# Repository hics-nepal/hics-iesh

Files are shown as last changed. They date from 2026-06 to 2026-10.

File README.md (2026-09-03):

# HICS IESH v0.1

> **Institute-level context: `~/Documents/HICS/hics-docs/`** (start at `README.md`; folder
> map in `HICS-MAP.md`). Two decisions there affect this repo directly: **G9/D28** —
> installed school stations are calibrated on every channel that can be, with MQ staying a
> labelled proxy; and **G10** — this repo's `curriculum/` (5 modules, 25+ CDC-aligned
> activities) is to be *unified* with the learning platform, not duplicated. See
> `hics-docs/LEARNING-PLATFORM.md` §2–3.

> **⚠ Deploying or debugging a station? Read [`HANDOFF.md`](HANDOFF.md) first.**
> A live diagnosis on 2026-09-03 found the station had never logged a usable day of data:
> a continuous 5 V undervoltage, sensors dropping off their buses, and firmware that logged
> a dead sensor's last value forever (~46 % of the soil column was garbage that reached the
> website). The firmware is fixed; the hardware rebuild is not started. `HANDOFF.md` has the
> **[`HANDOFF.md`](HANDOFF.md) is the single document for that work** — the faults with their
> evidence, the repos and where truth lives, the rebuild, and what is still unverified.
> `docs/drawings/` has the wiring schematic and perfboard layout.

**Himalayan Institute for Contextual Sciences — Integrated Environmental Smart Hub**

An offline-capable environmental monitoring station built on Raspberry Pi. Collects live atmospheric, air quality, and soil data; streams it to a web dashboard; and delivers Nepal CDC-aligned science activities for Grades 6–Undergraduate.

---

## Hardware

| Component | Sensor / Module | Interface |
|---|---|---|
| Air temp & humidity | DHT22 | GPIO 23 |
| Barometric pressure | BMP280 | I2C 0x76 |
| OLED display | SH1106 128×64 | I2C 0x3C |
| Real-time clock | DS3231 | I2C 0x68 |
| Soil temperature | DS18B20 | 1-Wire GPIO 4 |
| Soil moisture | Capacitive (MCP3208 CH2) | SPI |
| CO gas | MQ-7 (MCP3208 CH0) | SPI |
| Air quality | MQ-135 (MCP3208 CH1) | SPI |
| Sky camera | RPi Camera v1.3 OV5647 + fisheye | CSI |
| ADC | MCP3208 8-ch | SPI CE0 |

---

## Quick Start

**Flash a new SD card and have the RPi fully running in one command:**

```bash
# Insert SD card, then:
sudo bash flash.sh --wifi-ssid "YourNetwork" --wifi-password "YourPassword"
```

Then insert the card into the RPi, connect power, and wait 5–10 minutes. Done.

> **Hostname:** The RPi will be reachable at `iesh.local` on any network it joins.

---

## Flashing an SD Card

### What `flash.sh` does

1. Flashes Raspberry Pi OS to the SD card
2. Enables SSH and creates the `pawan` user
3. Configures WiFi
4. Copies all HICS code to the card
5. Installs a first-boot service that automatically installs all dependencies and starts the HICS services on first power-on

The OS image expands to fill the entire SD card on first boot — a 128 GB card will use all 128 GB.

### Requirements

- Linux machine with the SD card inserted
- `sudo` access
- Tools: `dd`, `xzcat` (`xz-utils`), `rsync`, `partprobe` (`parted`)
- Raspberry Pi OS image (`.img` or `.img.xz`) — download from [raspberrypi.com/software/operating-systems](https://www.raspberrypi.com/software/operating-systems/) or use the one in `~/Downloads`

### Usage

```bash
# Basic (will prompt for WiFi)
sudo bash flash.sh

# Full options
sudo bash flash.sh \
  --image ~/Downloads/2026-04-21-raspios-trixie-arm64-lite.img.xz \
  --device /dev/sda \
  --wifi-ssid "MyNetwork" \
  --wifi-password "MyPassword" \
  --hostname "hics-iesh" \
  --station-id "IESH-KMC-001" \
  --api-key "<key issued by himalayansciences.org>"

# Only flash OS without copying HICS code
sudo bash flash.sh --skip-code
```

| Option | Default | Description |
|---|---|---|
| `--image PATH` | auto-detect `~/Downloads/*.img.xz` | OS image file |
| `--device DEV` | `/dev/sda` | SD card device (confirmed before writing) |
| `--wifi-ssid` | (prompted) | WiFi network name |
| `--wifi-password` | (prompted) | WiFi password |
| `--hostname` | `hics-iesh` | RPi hostname |
| `--password` | random, printed at end | `pawan` user password — per-device, never shared |
| `--station-id` | (none) | Station ID for cloud sync, e.g. `IESH-KMC-001` |
| `--api-key` | (none) | Station API key from himalayansciences.org |
| `--skip-code` | false | Skip copying HICS code |

### After First Boot

First boot takes **5–10 minutes** while packages install. When complete:

```bash
# Find the RPi on your network
ping hics-iesh.local

# SSH in
ssh pawan@hics-iesh.local   # password: printed once by flash.sh

# Check first-boot completed
cat ~/hics-firstboot.log

# Check services
sudo systemctl status hics-core hics-web
```

Open the dashboard in any browser: **`http://iesh.local:5000/`**

---

## Manual Setup (no flash.sh)

If you already have RPi OS running and just want to install HICS:

```bash
# On RPi — copy code first, then:
sudo bash ~/hics/setup.sh
```

`setup.sh` installs packages, enables hardware interfaces, configures the DB path, installs systemd services, and runs sensor tests. Safe to re-run.

---

## Accessing the Station

### Via Hotspot (field use — no router needed)

Connect any phone/tablet/laptop to the Pi's WiFi hotspot:

| | |
|---|---|
| **WiFi name** | `IESH_Hub` |
| **Password** | per-device — set/generated by `scripts/setup_hotspot.sh`, written on the station label |
| **Dashboard** | **`http://iesh.local`** ← just type this |
| **SSH** | `ssh pawan@iesh.local` |

> Port 80 redirects automatically to Flask on 5000 — no port number needed.

### Via existing network

| URL | Description |
|-----|---|
| `http://iesh.local:5000/` | Main dashboard — mDNS (works on all interfaces) |
| `http://iesh.local:5000/camera` | Sky camera — live stream + still |
| `http://iesh.local:5000/learn` | Learning portal — 5 modules, 25+ activities |

Default SSH: `ssh pawan@iesh.local` — per-device password set at flash time

---

## SD Card Migration (moving to a bigger card)

```bash
# 1. Flash new card (same command as above)
sudo bash flash.sh --wifi-ssid "..." --wifi-password "..."

# 2. Optionally copy existing database to new card
#    (connect old RPi via SSH first, or mount old card)
scp pawan@<old-ip>:~/hics-data/hics.db /tmp/hics.db
# Then after flashing and booting:
scp /tmp/hics.db pawan@<new-ip>:~/hics-data/hics.db
```

The data directory (`~/hics-data/`) is separate from the code so the database survives code updates and re-flashes.

---

## Creating a Reusable Custom Image

After the RPi is fully set up, you can create a custom `.img.xz` to flash to other cards instantly (no first-boot wait):

```bash
# On development machine, with RPi card inserted as /dev/sda:
# (RPi must be powered off and card removed)

# Shrink partitions first (optional but recommended)
sudo apt install pishrink
sudo pishrink.sh /tmp/hics-custom.img   # if you dd'd first

# Or just dd the card directly:
sudo dd if=/dev/sda bs=4M status=progress | xz -T0 > hics-custom.img.xz
```

This image can be flashed to any card with `flash.sh --image hics-custom.img.xz --skip-code` (code is already embedded) or standard tools.

---

## Development Workflow

Two update paths exist depending on where you are in the cycle:

| Situation | Command |
|---|---|
| Iterating on hardware code, Pi on desk | `./deploy.sh --restart` |
| Pushed a fix to GitHub, Pi anywhere | `./deploy.sh --pull` |
| Setting up a brand-new Pi | `git clone`, then set API key in `sensors/config.py` |

```bash
# Sync local changes to the Pi + restart services
./deploy.sh --restart

# Pull latest committed code from GitHub on the Pi + restart
./deploy.sh --pull

# Sync a single file without touching anything else
./deploy.sh --file sensors/dht22.py
```

> `sensors/config.py` is **never** overwritten by `deploy.sh` — it holds the
> per-device API key and is managed directly on the device.
> See `sensors/config.py` comments for details.

The `deploy.sh` script uses `rsync --relative` — never write bare `rsync` with
a list of source files; it silently flattens paths into the destination directory.

### Service management on RPi

```bash
sudo systemctl status hics-core hics-web      # check status
sudo systemctl restart hics-web               # restart web server
journalctl -u hics-web -f                     # live web logs
journalctl -u hics-core -f                    # live sensor logs
```

### Run sensor tests

```bash
ssh pawan@iesh.local "sudo python3 ~/hics/tests/test_all.py"
```

---

## Project Structure

```
hics-iesh-v0.1/
├── flash.sh                   ← Flash SD card (run on dev machine)
├── setup.sh                   ← Install/repair on running RPi (run on RPi)
├── deploy.sh                  ← Sync code from dev machine to RPi (see Development Workflow)
├── requirements.txt           ← Python dependencies
│
├── core_dash.py               ← OLED display + sensor loop + DB logger
├── terminal_dash.py           ← Terminal monitoring dashboard
│
├── sensors/
│   ├── config.py              ← All hardware config (single source of truth).
│                                 API_KEY is set per-device after cloning — never committed.
│                                 Git tracks this file with --assume-unchanged on the Pi.
│   ├── camera.py              ← Sky camera: capture, analysis, MJPEG stream
│   ├── bmp280_sensor.py       ← Pressure / temperature
│   ├── dht22.py               ← Air temp / humidity
│   ├── ds18b20.py             ← Soil temperature
│   ├── mcp3208.py             ← ADC: soil moisture + MQ gas sensors
│   ├── oled.py                ← SH1106 OLED display
│   └── rtc.py                 ← DS3231 real-time clock
│
├── data/
│   ├── database.py            ← SQLite read/write interface; tracks synced flag per row
│   └── uploader.py            ← Batch uploader — drains unsynced rows to himalayansciences.org;
│                                 accumulates offline, backfills on reconnect
│
├── web/
│   ├── app.py                 ← Flask app (port 5000)
│   ├── static/style.css       ← Shared styles
│   └── templates/
│       ├── index.html         ← Main dashboard
│       ├── camera.html        ← Sky camera page
│       ├── _nav.html          ← Shared navigation
│       └── learn/             ← Learning portal templates
│
├── curriculum/
│   └── modules/               ← 5 learning modules (climate, soil, air, data, environment)
│
├── scripts/
│   ├── firstboot.sh           ← Runs on RPi at first power-on (auto-setup)
│   ├── calibrate_soil.py      ← Soil moisture calibration
│   └── sync_rtc.py            ← RTC time sync utility
│
├── services/
│   ├── hics-core.service      ← Systemd: sensor loop
│   ├── hics-web.service       ← Systemd: Flask web server
│   └── hics-firstboot.service ← Systemd: runs firstboot.sh once
│
└── tests/
    ├── test_all.py            ← Master test runner
    ├── test_camera.py         ← Camera capture + sky analysis
    └── test_*.py              ← Per-sensor tests
```

---

## Cloud Sync

Every 5 minutes `hics-core` calls `upload_unsynced()`, which:

1. Reads all rows from the local SQLite DB that have not yet been synced
2. POSTs them in batches of up to 500 to `https://himalayansciences.org/api/v1/ingest/environmental/`
3. Marks each row `synced=1` on success

If the Pi is offline, rows accumulate locally. The next successful connection drains the full backlog automatically — no data is lost during outages.

### Configuring the API key

The API key is issued by the website server via `python manage.py seed_hics`. Set it once in `sensors/config.py` on the device:

```python
API_KEY     = 'paste-key-here'
API_NODE_ID = 'IESH-KMC-001'   # must match the Station registered on the server
```

The key is never stored in the git repo. On the Pi, the file is marked `--assume-unchanged` so `git status` stays clean.

### Checking sync status

```bash
# How many rows are waiting to be synced?
sqlite3 ~/hics-data/hics.db "SELECT COUNT(*) FROM telemetry WHERE synced=0;"

# Trigger a manual upload (useful after setting the API key for the first time)
cd ~/hics && python3 -c "from data.uploader import upload_unsynced; print(upload_unsynced(), 'rows synced')"

# Live upload log
journalctl -u hics-core -f | grep Upload
```

---

## Troubleshooting

### Web app won't start
```bash
journalctl -u hics-web -n 50 --no-pager
sudo lsof -i :5000       # check for port conflict
```

### Sensors reading None
```bash
sudo python3 ~/hics/tests/test_all.py   # run all sensor tests
i2cdetect -y 1                           # I2C bus scan
# Expected: 0x3C (OLED), 0x68 (RTC), 0x76 (BMP280)
ls /sys/bus/w1/devices/                  # 1-Wire (DS18B20)
```

### Camera not working
```bash
rpicam-hello --list-cameras             # should show OV5647
rpicam-still -o /tmp/test.jpg && ls -lh /tmp/test.jpg
# If not detected: check ribbon cable, then rerun: sudo bash ~/hics/setup.sh
```

### No data in charts (blank dashboard)
```bash
journalctl -u hics-core -n 30 --no-pager
sqlite3 ~/hics-data/hics.db "SELECT COUNT(*), MAX(timestamp) FROM telemetry;"
```

### First boot seems stuck
```bash
# SSH in and check the log
ssh pawan@hics-iesh.local
cat ~/hics-firstboot.log
sudo systemctl status hics-firstboot
```

### SD card / disk space
```bash
df -h
sqlite3 ~/hics-data/hics.db \
  "DELETE FROM telemetry WHERE timestamp < datetime('now','-30 days'); VACUUM;"
```

### WiFi (wlan1 internet adapter)
```bash
sudo nmcli dev wifi connect 'SSID' password 'PASSWORD' ifname wlan1
```

### Hotspot not broadcasting
```bash
nmcli con up IESH_Hotspot        # bring up manually
nmcli dev status                 # check wlan1 state
systemctl status hics-redirect   # check port 80→5000 redirect
```

---

## Learning Portal

**`http://<ip>:5000/learn`**

5 modules, 25+ activities for Grades 6–Undergraduate aligned with Nepal CDC:

| Module | Focus | Grade range |
|---|---|---|
| 🌡️ Climate | Temperature, humidity, pressure, altitude | 6–UG |
| 🌱 Soil | Moisture, temperature, agriculture | 6–UG |
| 💨 Air Quality | CO, gas sensors, AQI | 6–UG |
| 📊 Data Science | Statistics, sensor patterns | 6–UG |
| 🌍 Environment | Ecology, policy, altitude zones | 6–UG |

Grade 6–8 activities include live sensor visualizations (horizontal gauges, bar charts, sky camera, altitude zones) that update in real time from the station.

---

*Built by [HICS — Himalayan Institute for Contextual Sciences](https://himalayansciences.org)*

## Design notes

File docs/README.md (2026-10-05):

# IESH v0.2 — build documents

Everything generated for the rooftop rebuild, in one place. The narrative, faults, build
order and decisions are in [`../HANDOFF.md`](../HANDOFF.md); this page is the index of the
sheets and views you take to the bench. **Nothing here is hand-drawn** — regenerate with:

```bash
python3 scripts/gen_drawings.py      # sheets 1-4 + bench.html
docs/cad/render.sh                   # CAD renders, templates, numeric checks (~2 min)
```

## At the bench
[`../BOARD-BUILD.md`](../BOARD-BUILD.md) — **the live working doc for the board being built
now**: board coordinates, orientation anchors, layout map, power topology, steps and gates.
Hand-written and ticked off as the work happens, unlike everything else here.

## The rooftop plan
[`rooftop-plan.html`](rooftop-plan.html) — **the site plan as of 2026-10-05**: everything on the
water-tank stand, the Pi + camera head unit, cable map after the move, risks, the sky pipeline
and the gated build order. Supersedes the tile-and-mast layout in the CAD until that is redone.

## Also at the bench: `bench.html`
[`bench.html`](bench.html) — all four sheets, the key renders and the §14 gates on one
scrolling page. Open it on a phone or tablet next to the soldering iron.

## Sheets — `drawings/`
| # | File | Use it for |
|---|---|---|
| 1 | [`schematic.svg`](drawings/schematic.svg) | every net, named — the name is what you write on the wire |
| 2 | [`perfboard.svg`](drawings/perfboard.svg) | **what you solder from.** Where each block goes on the blank 100 × 150 board (57 × 37 holes), the separation rules, and the order of work with its gate |
| 3 | [`pinout.svg`](drawings/pinout.svg) | the 40-pin header with used pins coloured; every CAT5e core traced terminal → sensor pin |
| 4 | [`lid-layout.svg`](drawings/lid-layout.svg) | where to bond the standoffs and tie mounts, in mm from the lid centre — read from the CAD |

All four come from one net list in [`../scripts/gen_drawings.py`](../scripts/gen_drawings.py);
sheet 4 reads its positions from `cad/roofbox.scad`, so the sheets cannot drift from each
other or from the CAD.

## CAD — `cad/`
| File | What |
|---|---|
| [`roofbox.scad`](cad/roofbox.scad) | the container, Pi 3B+, HAT, buck, camera tower, hood table, mast, vase, cable runs — all at 1:1 |
| [`roofbox_check.py`](cad/roofbox_check.py) | the assertions a render cannot make: clashes, field, height, sky clearance, ribbon, lid cuts, glands, cable lengths |
| [`render.sh`](cad/render.sh) | regenerates everything below and runs the checks |

### Views — `cad/renders/`
| | | |
|---|---|---|
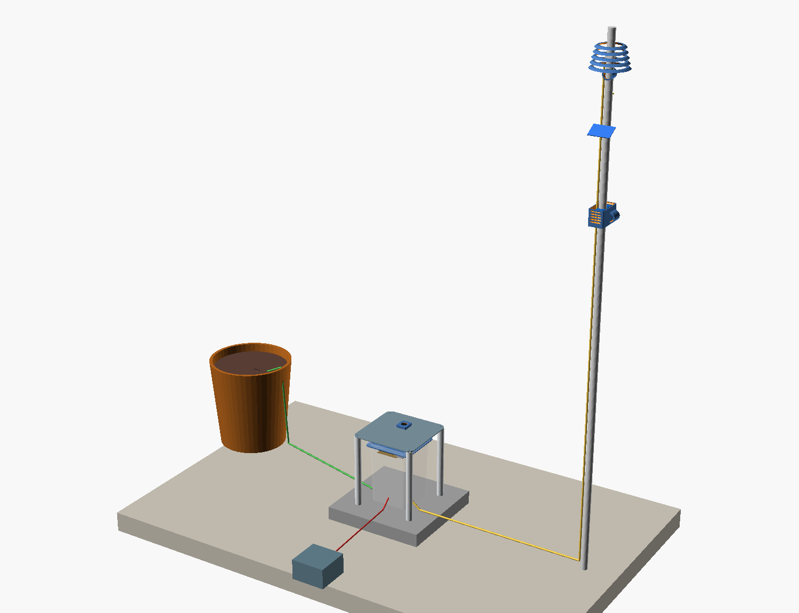
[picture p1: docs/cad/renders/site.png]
site
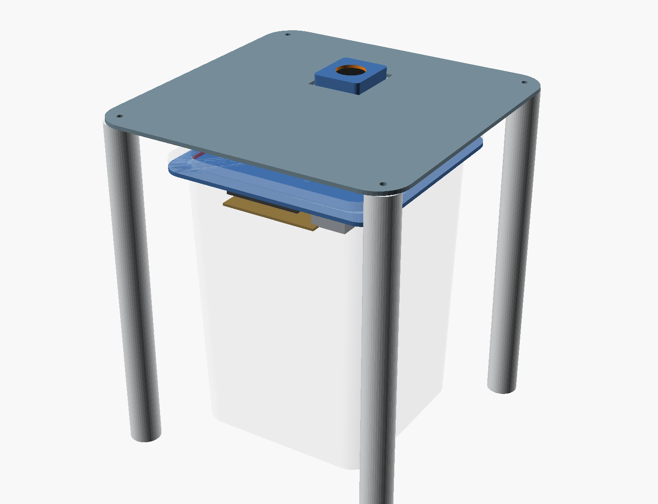
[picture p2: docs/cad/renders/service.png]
service
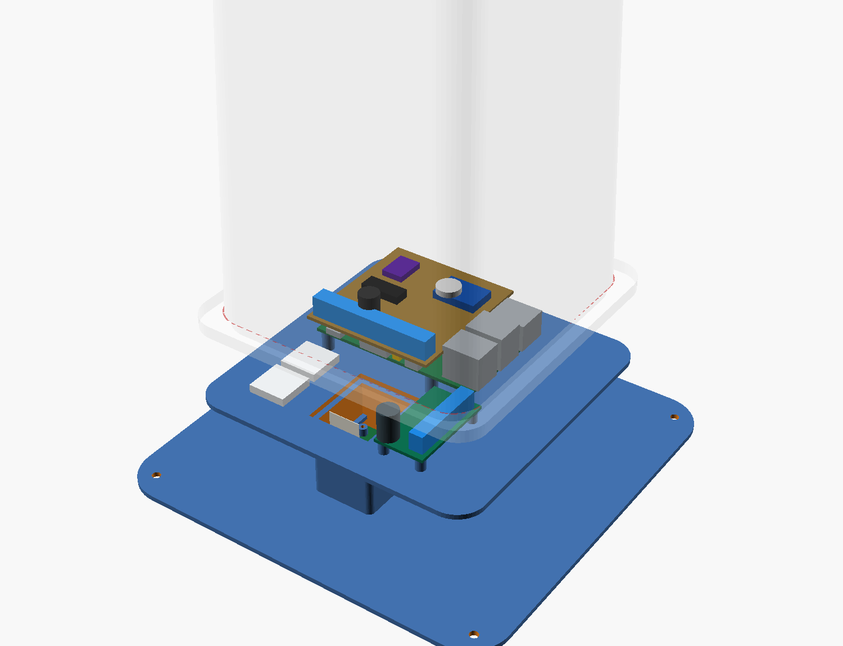
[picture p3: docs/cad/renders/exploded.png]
exploded
|  **site** — the whole station on the roof |  **service** — box on its tile, hood table, tower |  **exploded** — hood plate / lid stack / body |
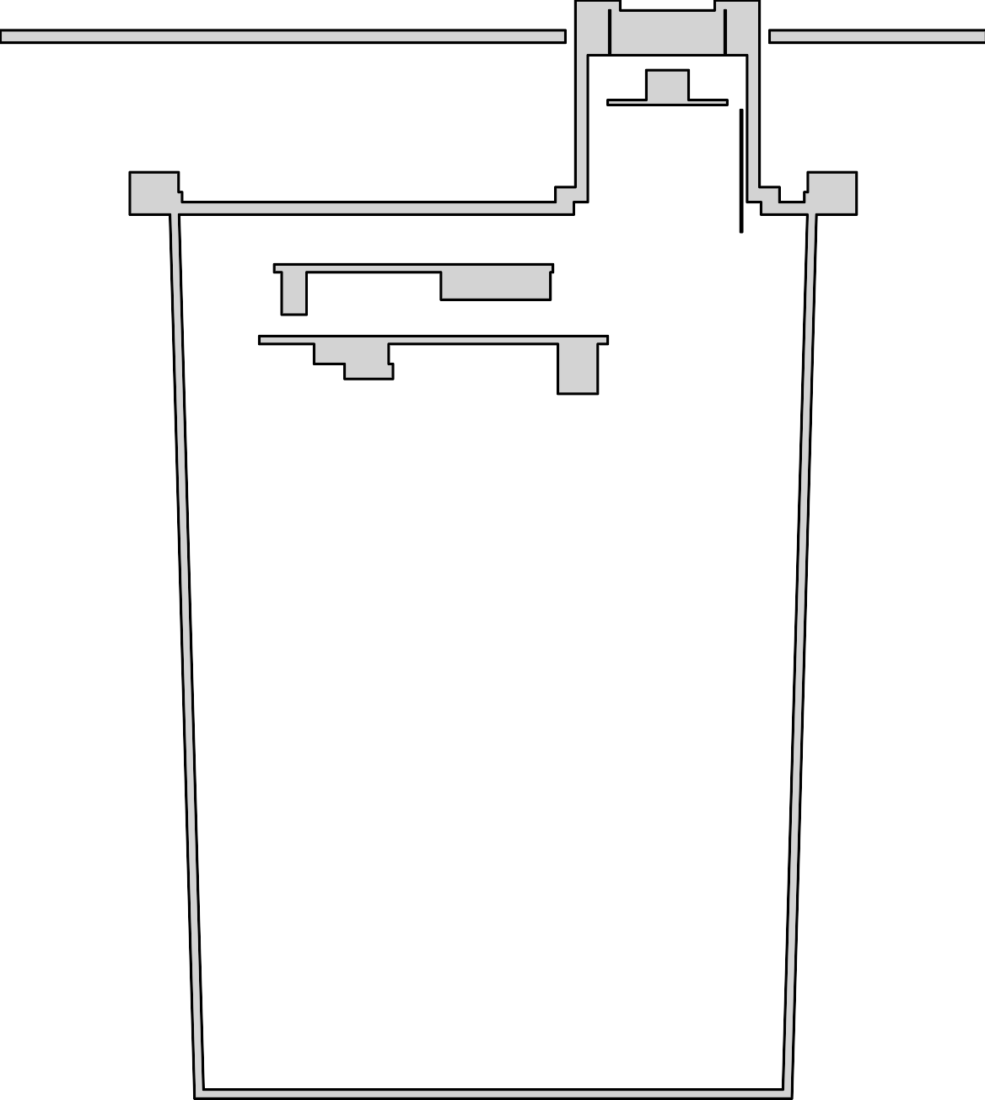
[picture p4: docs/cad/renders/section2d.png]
section2d
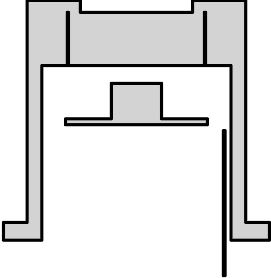
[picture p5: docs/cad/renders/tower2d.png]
tower2d
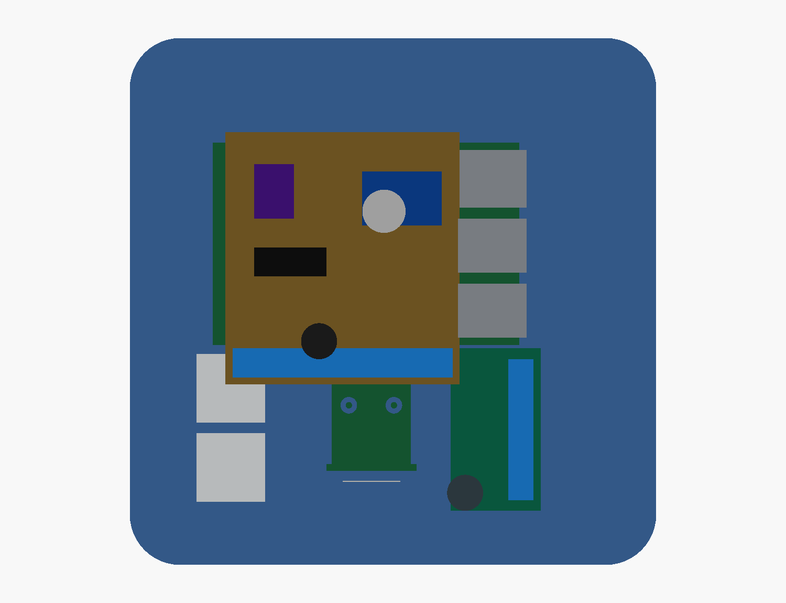
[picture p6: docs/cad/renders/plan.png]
plan
|  **section2d** — exact cut through the tower centre |  **tower2d** — lip, ring pocket, ledge, board |  **plan** — lid from the inside |
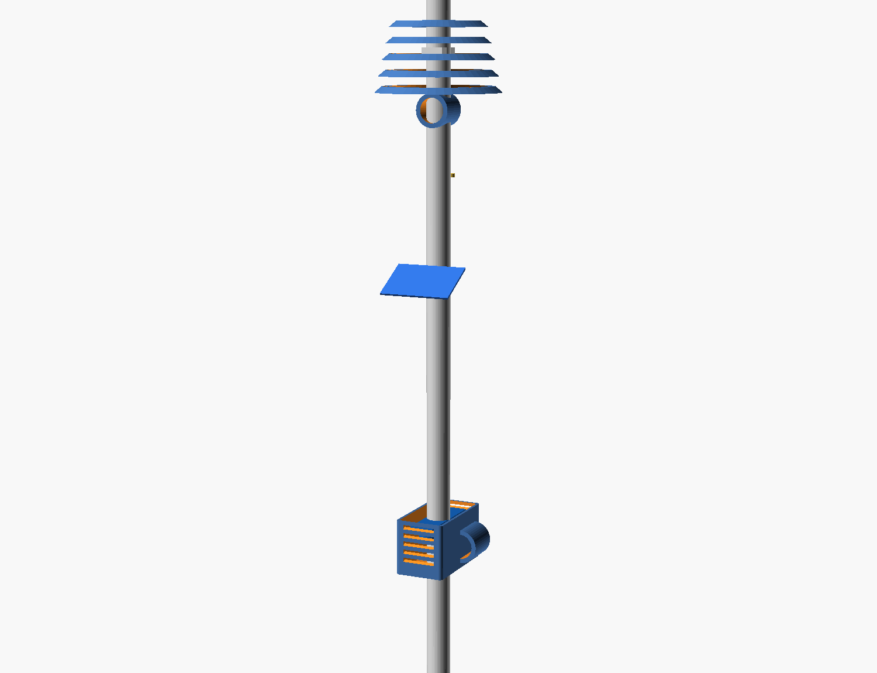
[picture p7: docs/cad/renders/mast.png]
mast
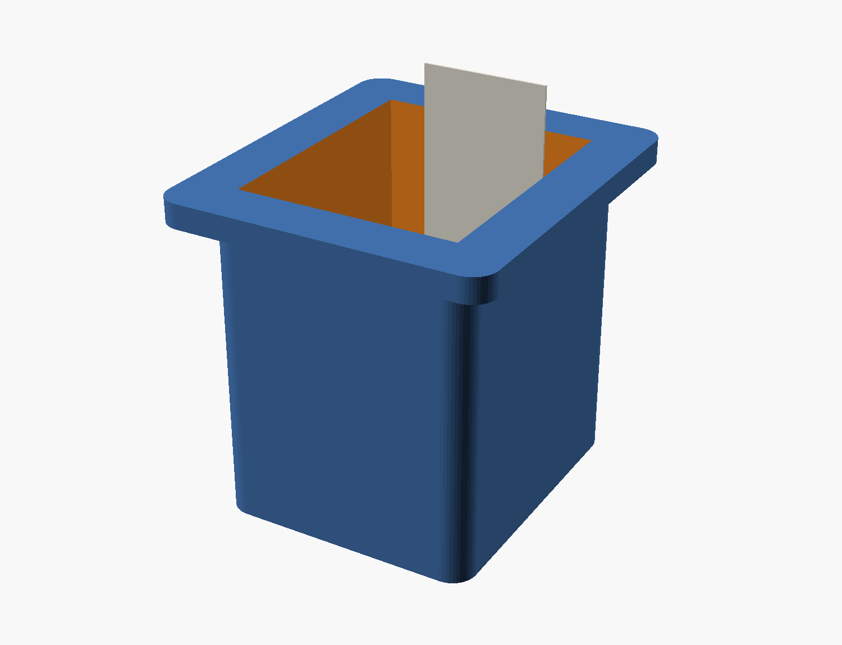
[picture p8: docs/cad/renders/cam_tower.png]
cam_tower
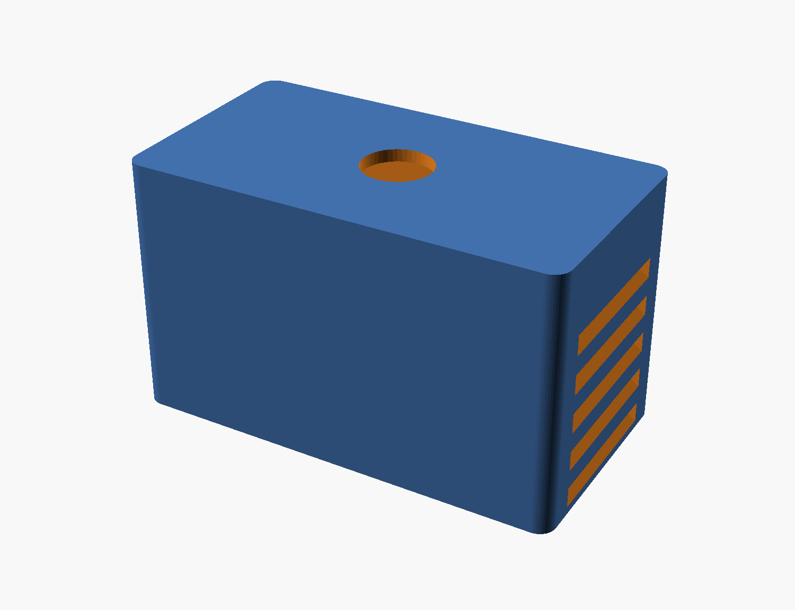
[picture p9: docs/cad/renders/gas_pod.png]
gas_pod
|  **mast** — shield, rain plate, gas pod |  **cam_tower** — the one printed part |  **gas_pod** · [shield](cad/renders/shield.png) |

### Templates — `cad/templates/` (SVG in mm; print at 100 %)
| File | Use |
|---|---|
| [`roofbox_lid.svg`](cad/templates/roofbox_lid.svg) | **placement** template for the lid underside: standoff marks, tie mounts, tower-bore witness, gasket band. Not a drilling template — today the lid is not drilled |
| [`roofbox_drill_wall.svg`](cad/templates/roofbox_drill_wall.svg) | one side wall, unrolled: three 12.5 mm PG7 holes 32 mm up, the 2 mm vent high under the hood |
| `roofbox_section2d.svg`, `roofbox_tower2d.svg` | the 2D sections, as vectors |

## Photos — `reference-photos/`
The as-built cardboard circuit (the fault), the container, its gasket, the camera and
fisheye. Captioned in HANDOFF §5.

## Station-side scripts — `../scripts/`
| | |
|---|---|
| `sudo scripts/pi_config.sh --dry-run` | shows the `config.txt` diff for HANDOFF §11; run without `--dry-run` to apply |
| `python3 scripts/gate_check.py` | the §14 commissioning gates as one PASS/FAIL table, on the Pi |
| `python3 tests/test_all.py --skip camera` | hardware tests in bring-up order |

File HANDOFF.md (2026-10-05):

# IESH v0.2 — handoff

> **The single document for this work** — everything a fresh session or a new person needs
> in order to pick it up and redo it in detail. Established **2026-09-03** from a live
> diagnosis of the station at `pawan@iesh.local`; audited and extended the same evening
> (§4 second pass, §16.8). **Bench-ready: start at [`docs/README.md`](docs/README.md)** for
> the sheets, then §14.
>
> Read §1 first if you don't know the repos; §3 for what is broken and how we know; §16 for
> what to question rather than inherit; §14 for what to actually do.
>
> **House rule, inherited:** *if this document and reality disagree, this document is the
> bug.* Sections marked **⚠ UNVERIFIED** were never confirmed — see §16.

## Contents

| § | |
|---|---|
| [0](#0-the-one-paragraph-situation) | The one-paragraph situation |
| [1](#1-the-repos-and-where-truth-lives) | **The repos and where truth lives** — hics-docs · this repo · iesh-production-reference · himalayansciences-web |
| [2](#2-what-is-physically-true-right-now) | What is physically true on the station right now |
| [3](#3-the-six-faults-with-their-evidence) | The six faults, with their evidence |
| [4](#4-what-changed-this-session--firmware-committed) | What changed this session — firmware, committed |
| [5](#5-reference-photographs-and-the-parts-inventory) | Reference photographs, dimensions, parts inventory |
| [6](#6-artifacts-and-how-to-regenerate-them) | Artifacts and how to regenerate them |
| [7](#7-the-one-design-decision-everything-follows-from) | **The one design decision everything follows from** |
| [8](#8-power--fix-this-before-anything-else) | Power — fix this before anything else |
| [9](#9-wiring--the-protoboard-hat) | Wiring — the protoboard rework |
| [10](#10-how-the-sensors-actually-connect) | How the sensors actually connect — CAT5e |
| [11](#11-pi-configuration-changes) | Pi configuration changes |
| [12](#12-sensor-placement-one-by-one) | Sensor placement, one by one |
| [13](#13-shopping-list) | Shopping list |
| [14](#14-build-order) | Build order, with gates |
| [15](#15-website--before-going-public-again) | Website — before going public again |
| [16](#16-the-rethink--what-to-question-rather-than-inherit) | **The rethink — what to question rather than inherit** |
| [17](#17--unverified--measure-or-confirm-before-relying-on-any-of-these) | ⚠ UNVERIFIED assumptions |
| [18](#18-open-decisions--not-for-an-agent-to-make-alone) | Open decisions — not an agent's to make alone |
| [19](#19-things-that-will-waste-your-time-if-you-dont-know-them) | Gotchas that will waste your time |
| [20](#20-what-this-deployment-does-not-claim) | What this deployment does *not* claim |

---

## 0. The one-paragraph situation

The station has **never logged a usable day of data**, and the reasons are now known rather
than suspected. The root cause is a **live 5 V undervoltage** that makes I²C and 1-Wire
devices drop off their buses intermittently; on top of that, v0.1's firmware logged a dead
sensor's last value forever, so roughly half the existing record is garbage that reached
the website looking like data. The firmware half is **fixed and committed**. The hardware
half is **not started** — the circuit is currently part-disassembled on the bench, the
camera is removed, and the undervoltage is still present on both supplies tried so far.
The immediate next action is not building anything; it is **making `vcgencmd get_throttled`
read `0x0` and keeping it there.**

### 0.1 ⚠ Site plan revised 2026-10-05: read before §7, §10, §12, §13

The site details are now known: a black **1000 L water tank on a ≈1 m iron-frame stand** with
an open-bar top, and **crows and monkeys** on the roof. The plan built on them is
**[`docs/rooftop-plan.html`](docs/rooftop-plan.html)** (rev 6). **Where it conflicts with
§7/§10/§12/§13, the plan wins.** Those sections get rewritten once a spot on the roof is chosen.

- ✅ **F6 closed, per Pawan 2026-10-05:** the OV5647 and the clip-on fisheye both work.
- **Settled:** the station is **one compact unit in the existing container**. The camera is in
  a lid tower under a small hood. The Pi and HAT sit on the shaded inside wall. Every outdoor
  sensor stays within ~0.5 m: the DHT22 shield on a short arm ≥300 mm from the box, the gas pod
  under the shelf, and the raindrop and LDR on the hood. The camera logs every sky object, not
  just meteors. New parts only if cheap and sold in Kathmandu; otherwise DIY.
- **Siting rule:** the lens needs no tall object within atan(Δh/d) > 15°, i.e. d ≥ 3.7 × Δh.
  First choice is a parapet or stairwell spot far enough from the tank. Fallback is a pipe at
  the stand corner above the tank.
- **Superseded:** the box on a tile, the large hood table, the sensor mast, the 8-core mast
  cable map (sheet 3), and the "drill the lid nowhere" rule.
- **Settled, power:** as built (BOARD-BUILD §2). 5 V 2 A into the GPIO feed, 1000 µF, 3.3 V
  from the Pi, heater rail on the other 5 V source. **No buck.** F1 is managed in software:
  `arm_freq=1000`, Bluetooth off, the sky pipeline at 640 × 480 on one core, the shortest 5 V
  lead (extend the mains side, not the 5 V side), and `get_throttled` logged and flagged. The
  LM2596 is only the last rung of the fallback ladder.
- **Settled, ribbon:** keep the 110 mm ribbon. The 100 × 150 HAT covers the camera connector
  (≈44 mm from the Pi's power end, ≈20 mm under the board), so the **only** orientation that
  can reach is: Pi on the inside wall, **USB/Ethernet end up** under the lid, ribbon out at the
  board's A-edge through the ~4 mm gap before the USB jack, short tower. Paper-strip test
  before fixing anything; the 30 cm ribbon (Himalayan Solution) is the fallback.
  ⚠ **Correction:** `roofbox_check.py`'s "110 mm FFC reaches (~90 mm)" was computed for a
  65 × 70 HAT that did not cover the connector. It does not hold for the board being built.
  Hanging the Pi from the lid (sheet 4) does not reach with this board.
- **Sequencing:** the Tools Competition Phase I abstract (13 Oct 11:59 PM ET = 14 Oct
  09:44 NPT; see `hics-docs/funding/tools-competition/2027/APPLICATION-PLAN.md`) comes first.
  That entry keeps IESH outside its claims, so station work after submission. Add a dew heater
  from day one: eight 220 Ω resistors on the heater rail.
- **Next bench session:** [`BOARD-BUILD.md`](BOARD-BUILD.md) → "▶ NEXT SESSION". It covers the
  paper-strip ribbon test, step 6 components, the new 20-way terminal map, `pi_config.sh`
  (now with the F1 trims), the power check under camera load, and the firmware tasks
  (CH3/CH4, health channels).

---

## 1. The repos and where truth lives

Four repositories matter. The rule from `hics-docs/WORKING-AGREEMENT.md`: **an
institute-level fact is stated once in `hics-docs` and linked everywhere else; a repo-level
fact lives in that repo's own truth document. Never restate across the boundary.**

```
~/Documents/HICS/
├── hics-docs/                     institute hub — strategy, funding, naming, decisions G1-Gn
├── hics-iesh/
│   ├── hics-iesh-v0.1/            THIS REPO — the firmware actually running on the station
│   └── iesh-production-reference/ productisation: PCBs, enclosure CAD, costing, roadmap
├── himalayansciences-web/         the Django site + the ingest API the station uploads to
└── imp/                           credentials — never read, quote or commit
```

### 1.1 `hics-docs/` — the institute hub
Loads in no session automatically; **open it.** Start at `README.md` (the board of external
deadlines, plus standing decisions G1–Gn), then `HICS-MAP.md` (every folder and where its
truth lives) and `WORKING-AGREEMENT.md`.

Decisions that bear directly on this work:
- **G9 / D28** — installed school stations are calibrated on every channel that can be, with
  **MQ staying a labelled proxy**. This is why `quality_flag = suspect` is correct, not a bug.
- **G10** — this repo's `curriculum/` is to be *unified* with the learning platform, not
  duplicated. Don't extend it here.
- **G29 (2026-08-26)** — the Himalaya AI / DeepGyan collaboration is **ended**. HICS has **no
  partners and no external adopters**. Do not describe either as one in any material.
- **Swiss Week is 21–25 Sep 2026, travel from 20 Sep.** The one hard external date this work
  feeds. Nepal Week (the Swiss cohort visiting Nepal) is 8–12 Mar 2027 — that is the chance to
  *show* a working station rather than describe one.

### 1.2 This repo — `hics-iesh-v0.1/`
The firmware on the station. Layout that matters:

| Path | What |
|---|---|
| `core_dash.py` | the sensor loop: reads, OLED, DB write, upload. **The main program** |
| `sensors/config.py` | single source of truth for pins, addresses, calibration, API key. **Never synced by `deploy.sh`** and `--assume-unchanged` on the Pi |
| `sensors/health.py` | **new this session** — the freshness + plausibility gate (§4) |
| `sensors/*.py` | one driver per device: `dht22` `bmp280_sensor` `ds18b20` `mcp3208` `oled` `rtc` `camera` `air_quality` |
| `data/database.py` | SQLite interface. Every sensor column is nullable |
| `data/uploader.py` | batch upload to the website, with a `synced` flag per row |
| `web/app.py` | Flask dashboard on :5000 (dev server — fine for LAN) |
| `curriculum/` | 5 modules, 25+ activities. **Frozen pending G10** |
| `scripts/gen_drawings.py` | **new** — generates both 2D sheets from one net list |
| `tests/test_health.py` | **new** — 21 checks, runs with no hardware |
| `deploy.sh` | rsync to the Pi. `--restart` · `--pull` · `--file` |
| `flash.sh` / `setup.sh` | provision a blank SD card / repair a running Pi |

Station DB lives at `~/hics-data/hics.db` on the Pi — deliberately outside the code tree so
it survives re-deploys and re-flashes.

### 1.3 `../iesh-production-reference/` — the product, and it already exists
**Read this before proposing any hardware design.** It is a reference library, not the
product itself, and it is further along than you might assume. Decisions are registered as
D1–D29 in `07-roadmap/02-decisions-register.md`.

| Folder | What's in it |
|---|---|
| `00-overview/` | product vision, the two-track EDU/SCI strategy, current-state audit |
| `01-hardware/` | v0.1 teardown, calibration, **`04-power-architecture.md` (authoritative, numeric)** |
| `02-pcb/` | **two routed boards, DRC-clean, gerbers ready to fab** |
| `03-enclosure/` | OpenSCAD CAD for both variants, a browser 3D viewer, print STLs |
| `04-costing/` | BOM costing, pricing, unit economics |
| `05-modular-platform/` | the plug-and-play module architecture and use-case configs |
| `06-firmware-data/` | firmware production-readiness, ingest contract, OTA/fleet |
| `07-roadmap/` | phased plan, milestones, **decisions register D1–D29**, risks |

**The two PCBs — already designed, not yet fabbed:**
- **`carrier-hat-v1`** — 65 × 70 mm, 2-layer, DRC 0/0. Gerbers at
  `02-pcb/carrier-hat-v1/out/fab/carrier_hat_v1_gerbers.zip`.
  ⚠ **J1 (the 40-pin socket) is on the BOTTOM copper** so the HAT seats down onto the Pi.
  The protoboard layout in §9 deliberately matches this footprint so it transfers.
- **`power-mgmt-v1`** — 60 × 46 mm. LT3652 MPPT charger (wall DC *and* solar), 2× LM74700
  ideal-diode OR, 2× TPS3808 supervisors.
  ⚠ **Input is 18–24 V, not 12 V** — a buck charger needs Vin above pack voltage. **Do not
  wire this into the Lalitpur deployment**; it belongs to the production build.

**Power tiers** (`01-hardware/04-power-architecture.md`) — *field ≠ remote*: the difference
is the charge source and battery size, not the topology.
1. **indoor / mains-primary** — `EDU-BASE`, `KIT`
2. **powered outdoor site** — `SCI-AIR`, `SCI-BUILDING`. **← the Lalitpur rooftop is this one**
3. **off-grid** — `FIELD-REMOTE` (Dolpo transect): solar + large LiFePO₄ + low-power firmware

**Enclosure CAD** in `03-enclosure/cad/`: `edu.scad` (desk/classroom), `sci.scad` (sealed
outdoor), shared `iesh_lib.scad`, and **`roofbox.scad` — added this session** for the found
container. `viewer.html` + `serve.sh` give a browser 3D view; `build_glb.py` bakes GLBs.

⚠ **Three traps in that folder:**
- **It is not a git repository.** Everything in it, including this session's CAD, is
  unversioned. See §18.
- **`iesh_lib.scad` models a Raspberry Pi 4B.** The deployed station is a **3B+**. That is
  why `roofbox.scad` defines its own board dimensions rather than reusing the library's.
- **`cad/render_views.py` has a stale hardcoded path** —
  `~/Documents/HICS/iesh-production-reference`, missing the `hics-iesh/` segment. It will
  fail until fixed. Not touched this session.

### 1.4 `../../himalayansciences-web/` — the site and the ingest API
Django + Wagtail. `hics/settings/base.py` has **`USE_TZ = True`, `TIME_ZONE = 'Asia/Kathmandu'`**
and `HICS_PRIMARY_STATION_ID = 'IESH-KMC-001'`.

**The contract is `docs/INGEST_CONTRACT.md`** — read it before changing anything in
`data/uploader.py`. Authoritative implementation: `instruments/api.py` and
`instruments/authentication.py`.

```
POST https://himalayansciences.org/api/v1/ingest/environmental/
Authorization: Token <station-api-key>
{"station_id": "IESH-KMC-001", "readings": [{...}, {...}]}
-> 201 {"accepted": n, "duplicates": n, "errors": n}
```

| Route (`/api/v1/…`) | Auth | Purpose |
|---|---|---|
| `ingest/environmental/` | Token | the station's upload endpoint |
| `stations/` | public | station list / GeoJSON. **Filters `status in (active, maintenance)`** |
| `data/latest/` | public | latest reading, `?station=IESH-KMC-001` |
| `data/historical/`, `data/aggregate/`, `data/compare/`, `data/download/` | public | series, rollups, CSV |
| `health/`, `stats/` | public | platform |

**Models** (`instruments/models.py`):
- **`Station`** — `station_id` · lat/lon/`altitude_m` · `location_name` · `status`
  (`active` / `offline` / `maintenance` / `planned`, default `planned`) · **`api_key_hash`**
  (SHA-256; the plaintext key is unrecoverable) · `last_seen` (stamped on every authenticated
  ingest). **It is a Wagtail snippet — edit it in the CMS**, so flipping `status` is an admin
  action, not a shell command.
- **`EnvironmentalReading`** — wide nullable columns (`temperature_c`, `humidity_rh`,
  `pressure_hpa`, `altitude_m`, `pm1_0/2_5/10`, `co2_ppm`, `co_ppm`, `uv_index`,
  `soil_temp_c`, `soil_moisture_pct`) **plus a `module_data` JSON blob** for everything else.
  That blob is the extension point — raw `mq7_raw`/`mq135_raw` land there, and new channels
  need no migration. Promote a channel to a column only once it stabilises.

**Four behaviours to know:**
1. **Dedup is `get_or_create` on `(station, timestamp)`.** Re-POSTing a window is safe and is
   how offline backfill reconciles — but it also means **a corrected row will never overwrite
   a bad one at the same timestamp.** This is why fault F4 (wrong clock) is permanent, and why
   §15 exists.
2. **Field aliases are accepted** — `air_temp`, `air_hum`, `pressure`, `soil_temp`,
   `soil_moist` map onto the canonical names, so the v0.1 payload works unchanged. New code
   should send canonical names; this repo now does.
3. **Any `v0.*` firmware marks every reading `suspect`**, whatever the values. Deliberate:
   uncalibrated sensors, an MQ proxy, unverifiable timestamps. Matches `hics-docs` G9. **Do
   not bump `FIRMWARE_VERSION` to clear it.**
4. **Plausibility bounds** in `_auto_quality_flag` — `sensors/health.py` deliberately mirrors
   them, so a value the server would reject is dropped at the device edge. **Keep the two
   lists in step.**

**API keys** are issued by `python manage.py seed_hics`
(`pages/management/commands/seed_hics.py`), or rotated with `Station.generate_api_key()`
(`secrets.token_urlsafe(32)`). Only the hash is stored — the plaintext is printed once, then
lives on the device in `sensors/config.py`. Auth is rate-limited to 10 req/min, and the
station is identified by the `station_id` in the body (or `?station=`), then the key checked
against that station's hash.

---

## 2. What is physically true right now

Verified by SSH on 2026-09-03, not assumed.

| Thing | State |
|---|---|
| Board | **Raspberry Pi 3B+** (not a 4B — `iesh_lib.scad` models a 4B, which matters for CAD) |
| Power | ⚠ **`throttled=0x50005` — under-voltage NOW, currently THROTTLED.** Measured on a 2-minute-old boot, so not stale history. Present on the original power bank *and* on the replacement plug adapter. |
| I²C | `0x3c` OLED ✅ · `0x57` DS3231 EEPROM ✅ · `0x68` DS3231 RTC ✅ · **`0x76` BMP280 ABSENT** ❌ |
| 1-Wire | `28-062261761e24` present — but it **disappeared and reappeared** during a single session |
| DS3231 | Responds, but reads **`2000-01-05`** — coin cell flat or never set. No `/dev/rtc0`: the overlay isn't loaded, so the OS never uses it |
| Camera | **Physically removed.** `config.txt` still has both `camera_auto_detect=1` and `dtoverlay=ov5647` (conflicting) |
| Network | `wlan0` on `liverpool08_2.4`, signal 70. **No `wlan1`** — a 3B+ has one radio, so the `IESH_Hub` hotspot in the README does not exist on this unit |
| DB | 749 rows total. Rows/day: Jun 11 → 598, Jun 12 → 35, Jun 13 → 101, Sep 3 → 26. A full day is 1440 |
| Services | `hics-core` + `hics-web` enabled and running |
| Website | Station exists and ingest works; deliberately **not** in the public list (`status` outside `active`/`maintenance`) until this round is done |

### Which product tier this is
This is **not** the EDU desk/classroom object. A rooftop unit at a home or a school —
weatherised, mains present, battery for ride-through, nobody handling it — is exactly
tier 2, *"powered outdoor site (field)"*, in
`../iesh-production-reference/01-hardware/04-power-architecture.md`, and it maps onto
`CONFIG-SCI-BUILDING` rather than `CONFIG-EDU-BASE`. That matters for three reasons:

- **No OLED window, no demonstrative cutaway, no handling affordances.** The sealed SCI
  variant has no display for a reason; the OLED stays on the sled for bench work only.
- **Field ≠ remote.** Grid is present, so there is no solar sizing problem and no large
  LiFePO₄ pack — a modest UPS ride-through is the whole battery requirement.
- The learning portal still runs and is still reachable on the LAN; it just isn't what
  the *enclosure* is designed around.

---

## 3. The six faults, with their evidence

Referenced as F1–F6 throughout. **F1 is the root cause and F2 is its main symptom — those
two are what the rebuild is for. F3 is fixed in firmware (§4).** F5 is the one that matters
to anyone outside this document: the station has never run a full day.

| # | Fault | Evidence |
|---|---|---|
| **F1** | **Undervoltage, continuously** | `vcgencmd get_throttled` = `0x50005` → *under-voltage NOW · currently THROTTLED*. `dmesg`: `hwmon2: Undervoltage detected!`. Present on the power bank **and** on the replacement plug adapter, both measured on a 2-minute-old boot — so it is not stale history. Pi **3B+** wants a solid 5 V/2.5 A. |
| **F2** | **Sensors drop off their buses and come back** — [see the as-built photo](docs/reference-photos/01-circuit-as-built-cardboard.jpg) | BMP280 `[Errno 121]`, OLED `[Errno 5]`, DS18B20 absent from `/sys/bus/w1/devices/` then present as `28-062261761e24` minutes later. Downstream of F1, and of ~40 dupont crimp + friction joints. |
| **F3** | **A dead sensor logged its last value forever** | v0.1 initialised every reading to `0.0` and overwrote only on success. Measured in the station DB: `soil_temp` = **441 rows of 0.0** + **15 rows of 85.0** (the DS18B20 power-on-reset sentinel); `pressure` = **416 rows frozen at 800.647395954495** (bit-identical to 12 dp) + 26 rows of 0.0, against only **5** plausible rows. ~46 % of the soil column was garbage indistinguishable from data. |
| **F4** | **No working clock** | No `dtoverlay=i2c-rtc,ds3231`, so `/dev/rtc0` does not exist and the OS never reads the DS3231. The chip itself reads **2000-01-05** — coin cell dead or never set. Boot time came from systemd's saved clock, which is why services claimed "started Jun 13" on a 14-minute uptime. Every power cut mints rows with a wrong timestamp, and the server dedups on `(station, timestamp)` — so bad timestamps are **permanent**. |
| **F5** | **Never ran a full day** | Rows/day: Jun 11 → 598, Jun 12 → 35, Jun 13 → 101, Sep 3 → 26. A full day is 1440. There is no time series to speak of. |
| **F6** | Camera dead | `ov5647: i2c read error, reg: 300a = -5`; `config.txt` carries **both** `camera_auto_detect=1` and `dtoverlay=ov5647`. Camera has since been physically removed. |

---

## 4. What changed this session — firmware, committed

Commit `2acdd13` on `master`. **Synced to the Pi but not yet running** — the services were
never restarted (`deploy.sh --restart` can't do it; the `sudo` step needs a TTY password).
That is *not* a loose end to chase: the station is being torn down and rebuilt, so the
restart happens naturally during bench bring-up (§14 step 4). It matters only that you know
the code on disk is newer than the code in the running process, so **the log you see before
a restart is v0.1's behaviour, not the fixed behaviour.**

| File | Change |
|---|---|
| `sensors/health.py` **(new)** | A `Channel` logs a value only if it is *fresh* (a reading arrived within `max_age`, default 180 s) **and** *physically plausible*; otherwise `NULL`. Bounds mirror `_QUALITY_BOUNDS` in the website's `instruments/api.py`, so anything the server would flag `suspect` is dropped at the edge — which catches `85.0` (above the 80 °C ceiling) and `0.0` hPa (below the 300 hPa floor) for free. Also detects a **frozen register** (bit-identical raw reads N times running) and recovers when it moves again. |
| `core_dash.py` | Values flow through a `ChannelSet` instead of floats initialised to `0.0`. Downed BMP280/OLED are re-initialised every 60 s, so a device that drops off and returns recovers without a service restart. Unhealthy channels are named in the log and on the OLED. Altitude no longer feeds 0.0 hPa into the barometric formula to display 44 330 m. |
| `sensors/ds18b20.py` | Rescans the 1-Wire bus on failed reads; rejects the 85.0 sentinel; checks CRC; calls `modprobe` by absolute path (it had been silently printing `modprobe: not found` — `/usr/sbin` isn't on a login user's `PATH`). |
| `sensors/bmp280_sensor.py`, `sensors/oled.py` | Added `reinit()`. BMP280 exposes `last_raw_p` for frozen detection. |
| `data/uploader.py` | The `_online()` probe socket was never closed — **one leaked fd per upload cycle, ~288/day**. Timestamps now sent as explicit UTC per `docs/INGEST_CONTRACT.md`; **verified instant-identical** to what Django was already storing via `TIME_ZONE`, so **no existing data shifts**. Floats rounded. |
| `sensors/__init__.py` | Driver re-exports made lazy (PEP 562). They were eager, so `sensors.config` and `sensors.health` — which need no hardware — could not be imported off-Pi or in CI. |
| `tests/test_health.py` **(new)** | 21 checks, every case a value found in the live DB. Runs anywhere: `python3 tests/test_health.py`. Passing on dev **and** on the station. |

**The design principle, if you change nothing else:** `NULL` is honest, a stale number is
not. `data/database.py` already declared every sensor column nullable; v0.1 simply never
wrote one.

### Second pass, same evening — audit of the above, committed

| File | Change |
|---|---|
| `sensors/health.py` | **Bug in the frozen-register gate.** It compared the *compensated value* when no raw word was given, so a DS18B20 buried in still soil (identical 0.0625 °C reads for minutes) or a DHT22 at a steady 0.1 °C would be declared *frozen* and logged `NULL` — the 24 h bench gate (§14 step 6) would have failed on healthy sensors. Frozen detection now runs **only** when the caller supplies `raw` (the BMP280 does). Two regression tests added; 23 checks pass. |
| `core_dash.py` | Removed the BMP280-as-`air_temp` fallback: the BMP280 sits inside a box that runs 45–55 °C in sun (§7), so that fallback would log the *box* temperature as air temperature whenever the DHT22 dropped out — exactly the plausible-looking garbage the gating exists to stop. ADC channels are handed `None` (not 0) when SPI never opened. |
| `tests/test_all.py` | `--skip camera` / `--only bmp280,oled,rtc`; test order is now the §14 step 5 bring-up order. |
| `scripts/pi_config.sh` **(new)** | Applies §11.1–11.3 to `config.txt` idempotently (`--dry-run` shows the diff). Backs up first. |
| `scripts/gate_check.py` **(new)** | The §14 gates as one command on the station: throttle flags, `config.txt`, RTC vs system clock, I²C scan, 1-Wire (with a 3 s re-scan to catch F2), services + the `| NULL:` log note, rows/day and today's NULL share. |
| `scripts/gen_drawings.py` | Schematic re-routed (no line crosses a rail or a label); terminals carry the **CAT5e core colour**; new sheets **3** (header pinout + cable map) and **4** (lid layout, dimensioned, read from the CAD). Mast cable core map changed — see §10. DHT22 moved to the 3.3 V pair. |
| `docs/cad/` **(moved here)** | `roofbox.scad` + `roofbox_check.py` + `render.sh` now live in this repo (§6). Design revised: camera **tower** through the hood, **free-standing hood table**, **no lid holes**, lens under a lip, PG7 hole size corrected (12.5 mm, not 7). §16.8 says why. |

---

## 5. Reference photographs and the parts inventory

### Photographs
In `docs/reference-photos/` (1400 px, ~850 KB total) so the docs don't depend on paths
outside the repo. **Several assumptions in §17 were read off these images — which is exactly
why they need calipers.**

**[`01-circuit-as-built-cardboard.jpg`](docs/reference-photos/01-circuit-as-built-cardboard.jpg)
— fault F2, visually.** The cardboard build as taken to the AIT selection pitch: dupont
plugged into dupont, joints held with masking-tape flags, no strain relief anywhere, sensor
boards hanging off unsupported leads. The black power bank at left was the original supply
(F1). This is the thing being replaced.

**[`02-container-exterior.jpg`](docs/reference-photos/02-container-exterior.jpg) — the found
enclosure.** *Re-measured 2026-09-11: **130 × 130 mm base, 170 × 170 mm top, 230 mm tall,
internal** — materially bigger than the 120 × 120 × 180 first recorded (§5 table).* The taper,
rim width and wall thickness in `roofbox.scad` were **estimated from this image** — U1.

**[`03-container-interior-gasket.jpg`](docs/reference-photos/03-container-interior-gasket.jpg)
— the red silicone gasket** in the lid channel. This is the reason the container is usable
at all, and the reason the lid is the chassis plate. The lid seats on a moulded rim, not on
the wall edge.

**[`04-camera-and-clipon-fisheye.jpg`](docs/reference-photos/04-camera-and-clipon-fisheye.jpg)
— the constraint that shaped the enclosure.** OV5647 "Raspberry Pi Camera Rev 1.3", board
**25 × 24 mm**, with its ribbon at **~110 mm — and that is what forces lid-up (§16.1)**.
Also the clip-on phone fisheye: a knurled-ring lens element on a hinged clip, which is what
`cam_tower` seats. `FE_RING_D`, `FE_RING_H` and `FE_BACK` (U2, U3) were all guessed from
this photo.

### Dimensions on record

| Item | Dimension | Source |
|---|---|---|
| Container body | **130 × 130 mm base, 170 × 170 mm top, 230 mm tall — all internal** | **re-measured 2026-09-11.** Supersedes the 120 × 120 × 180 previously recorded here as *measured* |
| Container taper / rim / wall | rim ≈8 mm, wall ≈1.8 mm | **still estimated — U1** |
| Camera board (OV5647 Rev 1.3) | 25 × 24 mm, M2 holes on a 12.5 mm grid | datasheet + photo |
| Camera ribbon | **≈110 mm** | measured |
| Fisheye knurled ring | ≈Ø23 × 9 mm | **estimated — U2** |
| Fisheye back-focal gap | ≈3 mm | **guess, needs trial — U3** |
| Raspberry Pi 3B+ | 85 × 56 mm, M2.5 on a 58 × 49 grid, ports 17 mm tall | datasheet |
| Protoboard in use | **100 × 150 mm** (`PY-10CM*15CM`), **uncut** | measured. The corrected box holds it flat in its top ~115 mm, so it is *not* trimmed to the 65 × 70 `carrier-hat-v1` footprint |
| Protoboard spares | 1 × 100 × 150 mm blank, 2 × 50 × 70 mm blank | measured |
| Verified stack height | ~~80.5 mm in 178 mm~~ | **stale — computed against the old box. Recompute once `roofbox.scad` is corrected** |

> ⚠ **The CAD has not caught up with the corrected box.** `roofbox.scad`, every render, both
> 1:1 templates and all of `roofbox_check.py` still model 120 × 120 × 180. Do not cut, drill or
> print from them until they are regenerated. The hood plate and leg lengths in §13 are
> likewise sized for the old box — ≈250 mm plate and ≈280 mm legs are the arithmetic for the
> real one, unconfirmed by the CAD.

### Parts inventory — transcribed from the three supplier bills
Supplier: **Supreme Light Technology Pvt. Ltd.**, Sanepa-2, Lalitpur · 9860563506 ·
sitech.com.np. Bill images are deliberately not committed; this transcription is the record.

**Bill 724 — 22 May 2026 — ₨7,095**

| Item | Qty | Rate | Item | Qty | Rate |
|---|---|---|---|---|---|
| DHT22 | 2 | 550 | LED | 5 | 2 |
| BMP280 | 1 | 350 | Resistors | 30 | 1 |
| Raindrop sensor | 2 | 250 | LDR | 4 | 15 |
| Soil moisture sensor | 1 | 165 | Multimeter + battery | 1 | 475 |
| Jumper wires | 2 sets | 150 | PIR sensor | 1 | 200 |
| MQ-7 | 2 | 370 | RTC module | 1 | 350 |
| MQ-135 | 2 | 300 | Matrix board 10×15 cm | 2 | 85 |
| OLED 1.3" | 1 | 750 | Matrix board 5×7 cm | 2 | 25 |
| TP4056 | 1 | 90 | 3.7 V Li-ion | 2 | 180 |
| MCP3208 | 1 | 625 | Li battery holder | 1 | 150 |

**Bill 745 — ~7 Jun 2026 — ₨3,885**

| Item | Qty | Rate | Item | Qty | Rate |
|---|---|---|---|---|---|
| Waterproof ultrasonic sensor | 1 | 950 | 2-channel relay | 2 | 250 |
| Ultrasonic sensor | 1 | 165 | Terminal block, 3-pin | 2 | 15 |
| Heatshrink tube 6 mm | 2 m | 30 | Raspberry Pi camera | 1 | 900 |
| Crocodile clips | 5 sets | 30 | Switch | 10 | 30 |
| Mic module | 1 | 150 | Buzzer | 1 | 30 |
| "Boom/boost module" | 1 | 650 | | | |

**Bill 884 — 11 Sep 2026 (083-5-26) — ₨890**

| Item | Qty | Rate | Item | Qty | Rate |
|---|---|---|---|---|---|
| Female header | 4 | 15 | MCP3208 | 1 | 650 |
| Capacitor (1000 µF) | 2 | 15 | Terminal block, 3-pin | 6 | 20 |
| Resistor (4k7) | 20 | 1 | Ceramic cap (100 nF) | 10 | 1 |

⚠ **₨15 each is single-row pricing** — a 2×20 dual-row female header is normally ₨50–80.
These are most likely 1×40 single-row strips, which work: two 1×20 pieces in adjacent
perfboard rows sit 2.54 mm apart and *are* a 2×20 header. Test that two strips seat
shoulder-to-shoulder in adjacent rows before soldering — some bodies are wider than 2.54 mm.

**Not stocked at SLT (11 Sep 2026):** CR2032/LIR2032 cell, and the 15-pin camera FFC.
The cell is available anywhere; the ribbon needs an online order (§16.1).

**What the inventory changes:**
- **Spares exist** for MQ-7, MQ-135, DHT22 and — since bill 884 — **MCP3208**. There is still
  **no spare BMP280** (U7).
- **Two 10 × 15 cm matrix boards, plus two 5 × 7 cm.** The corrected box takes a 100 × 150
  board flat, so **neither needs cutting** — build on the blank one and keep the rest.
- **A multimeter is on hand**, so F1 can be settled by measurement, not inference.
- ✅ **Terminals settled.** Bill 884 adds 6× 3-pin to the 2 on hand — 24 ways against the 14
  needed (8 + 4 + 2). Off the shopping list.
- **Unused and worth fitting:** raindrop ×2 (CH3 free), LDR ×4 (CH4 free).
- **Unused, no role here:** PIR, mic, buzzer, relays, switches. The *waterproof ultrasonic*
  is interesting later as a **snow-depth or water-level** channel — a Himalayan-transect
  story, not a Lalitpur-rooftop one.
- ✅ **U4 closed by purchase.** Rather than sort 30 unknown resistors, bill 884 buys 20
  known 4k7 at ₨1 each. Still meter them, and pick *matched pairs* for the MQ dividers —
  `MQ_DIVIDER_RATIO` (`sensors/config.py:26`) is `(R1+R2)/R2`, so put the measured value in
  rather than assuming 2.0.
- ❌ **U5 RE-OPENED 2026-09-13: it is NOT a buck.** The chip reads **`LM2587S`** — a *boost*
  (step-up) regulator. On the bench with 12 V in, it read 30 V and could not be trimmed below
  ~11.2 V (input minus a diode drop), which is boost behaviour. The 2026-09-11 "LM2596"
  identification was wrong and was never measured. **It cannot make 5 V from 9 or 12 V.**
  So 12 V→5 V is available on the bench already. **Set its output to 5.00 V on the meter
  before connecting anything** — these ship at arbitrary voltages, often 15–20 V, which would
  destroy both MQ modules. Honest rating is ~2 A; fit a heatsink.
- **Power needs no purchase.** A 5 V 2 A adapter feeds the Pi; a 9 V adapter through the
  LM2596 at 5.00 V feeds the MQ heaters alone, grounds common at the board. That is §8.3's
  split rail, built from parts on hand.

### Generated drawings and renders

Index with thumbnails: [`docs/README.md`](docs/README.md).

| Sheet | Path |
|---|---|
| 1 · Wiring schematic | [`docs/drawings/schematic.svg`](docs/drawings/schematic.svg) |
| 2 · Perfboard placement | [`docs/drawings/perfboard.svg`](docs/drawings/perfboard.svg) |
| 3 · Header pinout + cable map | [`docs/drawings/pinout.svg`](docs/drawings/pinout.svg) |
| 4 · Lid layout, dimensioned | [`docs/drawings/lid-layout.svg`](docs/drawings/lid-layout.svg) |
| Whole station on the roof | [`docs/cad/renders/site.png`](docs/cad/renders/site.png) |
| Box as it stands (hood table, tower) | [`docs/cad/renders/service.png`](docs/cad/renders/service.png) |
| Section through the tower (exact, 2D) | [`docs/cad/renders/section2d.png`](docs/cad/renders/section2d.png) |
| Exploded / plan / mast / tower / pod / shield | `docs/cad/renders/*.png` |
| Lid placement template (1:1) | [`docs/cad/templates/roofbox_lid.svg`](docs/cad/templates/roofbox_lid.svg) |
| Side-wall gland template (1:1) | [`docs/cad/templates/roofbox_drill_wall.svg`](docs/cad/templates/roofbox_drill_wall.svg) |

---

## 6. Artifacts and how to regenerate them

Everything generated lives under `docs/` and is indexed in [`docs/README.md`](docs/README.md).

| Artifact | Path | What it is |
|---|---|---|
| Build sheet | this document | faults, power, protoboard rework, CAT5e cabling, sensor placement, commissioning gates |
| Sheets 1–4 | `docs/drawings/*.svg` | schematic · perfboard placement · pinout + cable map · lid layout. **One net list feeds all of them** |
| Drawing generator | `scripts/gen_drawings.py` | **Edit the net list here, not the SVGs.** Sheet 4 reads its positions from the CAD file |
| Box + site CAD | `docs/cad/roofbox.scad` | the real container, Pi 3B+, HAT, buck, camera tower, hood table, mast, vase, cable runs. Parts listed in its header |
| Numeric checks | `docs/cad/roofbox_check.py` | XY clash, usable field, stack height, sky clearance, ribbon reach, lid penetrations, gland spacing, **cable cut lengths** |
| Renders + templates | `docs/cad/renders/`, `docs/cad/templates/` | PNG views; 1:1 SVG templates in mm |
| Bench page | `docs/bench.html` | all four sheets + the key renders + the §14 gates on one page for a phone at the bench |
| Station-side tools | `scripts/pi_config.sh`, `scripts/gate_check.py` | apply §11 · run the §14 gates |

Regenerate:
```bash
python3 scripts/gen_drawings.py      # sheets 1-4 + docs/bench.html
docs/cad/render.sh                   # every render + template, then the checks (~2 min)
```

> The CAD was moved here from `../iesh-production-reference/03-enclosure/cad/` (which is
> **not a git repository** — a pointer file `ROOFBOX-MOVED.md` was left there). `edu.scad`
> / `sci.scad` there are the product enclosures and stay put. That folder's
> `render_views.py` had a stale absolute path; fixed on disk 2026-09-03, unversioned.

---

## 7. The one design decision everything follows from

> **The box is a dry electronics vault. Every environmental sensor lives outside it.**

A sealed 170 mm box on a Lalitpur rooftop in September sun runs 45–55 °C inside. A
DHT22 in there measures *the box*, not the air — that single mistake is what makes most
DIY weather stations produce numbers that look fine and mean nothing. The MQ heaters
would also be reading their own exhaust.

So the unit is three physically separate things, not one box:

```
      [ radiation shield ]          hood (sun + rain)
       DHT22 air T / RH          ╔══════════════════╗
              │                  ║  ▲ fisheye sees  ║
   ┌──────────┴──────────┐       ╚═══════▲══════════╝
   │  SENSOR MAST        │           ┌───┴───┐  ← lid = chassis plate
   │   [ gas pod, MQ×2 ] │           │ Pi+HAT│     camera bolted under it
   │   [ LDR + raindrop ]│           │ buck  │     (110 mm ribbon reaches)
   └──────────┬──────────┘           │  BOX  │  130 base / 170 top × 230, LID UP
              │  CAT5e ─────────────▶│       │
              └──────────────────────│ ▣ glands in the SIDE WALL, low
                                     └───┬───┘
                        [ vase: DS18B20 + capacitive probe ]
```

**Orientation is forced by the camera ribbon, not chosen.** The ribbon on hand is
**110 mm** ([photo](docs/reference-photos/04-camera-and-clipon-fisheye.jpg)). An all-sky camera must look up, and the Pi must be within a ribbon's length
of it — so the camera sits in the lid with the Pi bolted directly beneath. Mounting the
box inverted (lid down) would put the Pi 180 mm from the sky-facing end and the ribbon
would not reach. A 300–500 mm FFC would free the choice; with this one, **lid up** is the
only layout that works.

**The hood is therefore mandatory, not a nice-to-have.** Lid-up means rain can sit on the
gasket, so the hood keeps direct rain off the seal. It is needed for solar gain anyway — a
sealed box in Kathmandu sun runs 45–55 °C inside — so one part solves both. It stands off
on legs: an air gap is what makes a shade work, and a hood touching the lid just conducts
the heat straight in. **The legs stand on the paving tile, not on the lid** (§16.8) — a
198 mm plate on four 20 mm PVC legs straddling the box, so nothing bolts through the seal
and the box lifts straight out from under it.

**The camera rides a printed tower up through the hood.** A fisheye flush in the lid under
a 32 mm hood sees a ~75° cone, not the sky. `cam_tower` (`docs/cad/`) carries the lens
6 mm proud of the hood plate; the ribbon path is ~90 mm of the 110 mm on hand.

**Cable glands move off the lid into the box side wall, low down**, so nothing faces the
sky. Drip loops below each.

**The fisheye lens is the window.** It's a [clip-on phone lens](docs/reference-photos/04-camera-and-clipon-fisheye.jpg): the element with its
knurled ring unscrews from the clip arm, and that ring beds into a sealed boss in the lid.
This is better than cutting an acrylic window — the camera isn't also shooting through an
extra sheet that would add reflections and haze. Vignetting into a circular image is
exactly what an all-sky camera wants.

**Build on a removable sled.** A flat plate (3 mm acrylic, ply, or ABS offcut) carrying
Pi + HAT + terminal strip, which drops into the box as a unit. Assembling inside a
box is miserable; assembling on the bench and then inserting is not. This is the
single biggest buildability win available.

---

## 8. Power — fix this before anything else

F1 is upstream of F2. Rebuilding the wiring on a sagging 5 V rail just produces
better-looking intermittency.

### Measure first, don't infer
You have a multimeter. With the station running and both MQ heaters on, measure between
**GPIO pin 2 or 4 (+5 V)** and **pin 6 (GND)**:

| Reading | Verdict |
|---|---|
| ≥ 5.00 V | supply fine — look elsewhere |
| 4.75–5.00 V | marginal; will fail under camera/WiFi peaks |
| < 4.75 V | this is F1. Fix the supply. |

The Pi's own flag is the other half of the same test:
```bash
vcgencmd get_throttled     # want 0x0 — anything with bit 0 or 2 set is live undervoltage
```

### The likely culprit is the cable, not the adapter
A thin micro-USB lead drops 0.5 V+ at 2 A no matter what the brick is rated for. In
order of what actually fixes it:

1. **Short, thick micro-USB cable** (≤ 1 m, 20 AWG power conductors). Cheapest test, and
   often the whole answer.
2. **A genuine 5 V / 3 A supply.** Not a power bank — a power bank's regulator sags under
   the MQ heater step load and many cut out at low draw.
3. **Feed the MQ heaters from their own 5 V rail, not through the Pi.** MQ-7 + MQ-135
   heaters are ~300–400 mA continuously and they switch; that step load on a shared rail
   is exactly what tips a marginal supply over. Common ground, separate +5 V. This is
   also what `../iesh-production-reference/01-hardware/04-power-architecture.md` does.

### Roof mains, and where the adapter goes
A wall-socket line is being run up to the roof, so there is mains at the station. That
settles the topology, with one caution: **no mains inside the instrument box.** A 240 V
adapter in a sealed plastic food container on a roof is not something to sign off.

So:

```
  indoor UPS (12 V lead-acid) ──AC──▶ roof socket ──▶ adapter in its OWN
                                                       small junction box
                                                            │ low voltage
                                                            ▼
                                                      gland ─▶ instrument box
```

- **Adapter lives outside the instrument box** — its own small weatherproof junction box,
  or under the hood, or in whatever housing the roof socket already has.
- **Only low voltage crosses into the vault.** Either 5 V on a short thick run, or 12 V
  into a small buck module on the chassis plate. Prefer **12 V + buck** if the adapter
  ends up more than about a metre away: 12 V draws ~2.4× less current for the same power,
  so the run loses far less voltage — and voltage drop *is* fault F1.
- **The UPS stays indoors**, feeding the roof circuit. That gives ride-through through
  Nepal's grid with no lead-acid battery sitting on a hot roof, which is where you want
  it: heat is what kills lead-acid.

> Do **not** wire the LT3652 power-mgmt-v1 board into this deployment. Its input is
> **18–24 V**, not 12 V, and it belongs to the production build.

---

## 9. Wiring — the protoboard HAT

> 🔧 **At the bench, work from [`BOARD-BUILD.md`](BOARD-BUILD.md)** — the live working doc for
> this build: the board's own A–Z/A′–J′ × 48→1 coordinates, the orientation anchors, the
> layout map, the power topology as settled, and the steps with their gates and tick boxes.
> This section is the reasoning behind it; that one is what you hold the iron next to.

Chosen over hardened jumpers because F2 *is* the joint count. Every dupont pair is a
crimp plus a friction fit; soldering replaces each with one joint. Off-board sensors keep
one deliberate, serviceable connection each, via screw terminals.

### Keep what is already soldered
The existing board already has the **MCP3208 soldered with its power lines** — that part is
already the right thing and there is no reason to redo it. The rework is *not* a rebuild:

| Keep | Replace |
|---|---|
| The soldered MCP3208 and its 3.3 V / GND / VREF lines | The **jumper-to-jumper chains between modules** — dupont plugged into dupont, held with masking tape. This is the F2 mechanism. |
| Any decoupling already fitted | Bare-wire twists and taped joints, wherever they carry a bus signal |
| The board outline, if it fits the sled | Unlabelled connections — every terminal gets an indelible-pen label |

So the job is: **cut the inter-module jumper chains out and replace each with a single
soldered run**, then terminate every *off-board* sensor at a screw terminal so it stays
serviceable. Nothing that is already a solder joint needs touching.

**The board does not need cutting.** The corrected box (§5: 170 mm across the top) takes a
full **100 × 150 mm** board flat in its upper ~115 mm, and a HAT is allowed to overhang the
Pi. Build on the *blank* 10 × 15 board rather than reworking the old one — stripping 25 wire
stubs and a field of solder blobs off heat-cycled pads is more work than starting clean.

To recover the MCP3208 from the old board without risking the IC: cut the old board into a
small island around it (the old board is disposable), then snip the island *between* the two
pin rows. Each pin is then near-free-standing and lifts with one touch of the iron.

The 65 × 70 `carrier-hat-v1` footprint is therefore **not** matched by this build. The zone
layout still transfers to the real PCB; the outline does not. That is the right trade for a
DIY station (§16.7).

### Pin map (from `sensors/config.py` — the single source of truth)

| Signal | GPIO | Header pin | Goes to |
|---|---|---|---|
| 3.3 V | — | 1, 17 | MCP3208 VDD+VREF, BMP280, OLED, DS3231, pull-ups, **DHT22**, soil probes, raindrop |
| 5 V | — | 2, 4 | MQ heaters only *(prefer a separate rail — §8)*. The DHT22 runs on 3.3 V on purpose: keeps its DATA at 3.3 V logic and off the heater rail |
| GND | — | 6, 9, 14, 20, 25, 30, 34, 39 | everything |
| I2C SDA | GPIO2 | 3 | BMP280 `0x76`, OLED `0x3C`, DS3231 `0x68` |
| I2C SCL | GPIO3 | 5 | same three |
| 1-Wire | GPIO4 | 7 | DS18B20 data (+ 4.7 kΩ to 3.3 V) |
| DHT22 data | GPIO23 | 16 | DHT22 (+ 4.7–10 kΩ to 3.3 V) |
| SPI MOSI | GPIO10 | 19 | MCP3208 pin 11 (Din) |
| SPI MISO | GPIO9 | 21 | MCP3208 pin 12 (Dout) |
| SPI SCLK | GPIO11 | 23 | MCP3208 pin 13 (CLK) |
| SPI CE0 | GPIO8 | 24 | MCP3208 pin 10 (CS/SHDN) |

### MCP3208 (16-pin DIP)
```
 CH0  1 ─┬─ 16  VDD    → 3.3 V
 CH1  2  │   15  VREF   → 3.3 V
 CH2  3  │   14  AGND   → GND
 CH3  4  │   13  CLK    → GPIO11 / pin 23
 CH4  5  │   12  Dout   → GPIO9  / pin 21
 CH5  6  │   11  Din    → GPIO10 / pin 19
 CH6  7  │   10  CS     → GPIO8  / pin 24
 CH7  8 ─┴─   9  DGND   → GND

 CH0 ← MQ-7 divider      CH1 ← MQ-135 divider      CH2 ← soil moisture AOUT
```

### The passives that are not optional

| Part | Where | Why |
|---|---|---|
| **4.7 kΩ** | DS18B20 DATA → 3.3 V | 1-Wire does not work without it. Its absence is a candidate cause of the DS18B20 dropping off the bus (F2). |
| **4.7 kΩ ×2 per MQ** | AOUT → node → GND, node → CHx | The 2:1 divider that keeps the MQ's 0–5 V out of a 3.3 V ADC input. `MQ_DIVIDER_RATIO = 2.0` in config depends on both being equal — measure them, don't trust the band. |
| **4.7–10 kΩ** | DHT22 DATA → 3.3 V | Bare DHT22 modules need one; 3-pin breakout boards already have it. Check yours before adding a second. |
| **100 nF** | across each sensor's supply pins | Local decoupling. |
| **470–1000 µF** | on the 5 V rail beside the MQ sensors | Absorbs the heater step load that destabilises the rail (F1/F2). |

> **Do not add I2C pull-ups.** The Pi 3B+ already has 1.8 kΩ on GPIO2/GPIO3. More
> resistors in parallel over-pull the bus. The right I2C fix is **shorter wires and a
> slower clock** — see §11.1.

### Layout discipline on the board
- Keep the I2C run **as short as physically possible** and route SDA/SCL side by side
  with a ground trace between or beside them.
- Solid ground: bond every ground pad into one continuous strip, tied to at least two Pi
  GND pins. A shared thin ground return is a classic source of exactly F2.
- Analogue apart from digital: put MCP3208 and the MQ dividers at the opposite end of the
  board from the DHT22 and the I2C header.
- **Label every screw terminal on the board itself** with an indelible pen. The masking
  tape flags on the cardboard version are the reason a rebuild is needed at all.

### Screw terminals
Needed: mast cable (8), soil cable (4), power in (2) — **14 ways**. Bill 884 adds 6× 3-pin
to the 2 on hand, so **24 ways are available** — settled.
Sheet 3 ([`pinout.svg`](docs/drawings/pinout.svg)) traces every way to its CAT5e core and
to the sensor pin it is soldered to at the far end.

---

## 10. How the sensors actually connect

The rule: **no sensor gets its own cable run.** Two multi-core cables leave the box — one
up the mast, one down to the vase — and each sensor taps the cable at its own end. That
takes the box from six penetrations to **two**, which is the difference between a box that
stays dry and one that doesn't.

### Use CAT5e for both runs
Cheap, sold on every corner in Kathmandu, 8 conductors, and the twisted pairs are exactly
what you want: each supply travels twisted with its own return, which is what keeps a
switching MQ heater from injecting noise into an analogue line running beside it. You
already have a length of it (the yellow cable in the bench photo).

Convention on both cables: the **solid** core of a pair carries supply or signal, the
**white-striped** core is that pair's return — so every current travels twisted with its
own return. Terminal way numbers match sheets 1 and 3.

**Mast cable — 8 conductors, all 8 used:**

| Way | Core | Carries | Solder to, at the mast end |
|---|---|---|---|
| 1 | orange | **+5 V** | MQ-7 VCC + MQ-135 VCC |
| 2 | orange-white | GND | MQ-7 GND + MQ-135 GND |
| 3 | green | **+3.3 V** | DHT22 VCC + raindrop VCC |
| 4 | green-white | GND | DHT22 GND + raindrop GND |
| 5 | blue | **DHT22 DATA** → GPIO23 | DHT22 DATA |
| 6 | blue-white | **raindrop AO** → MCP3208 CH3 | raindrop board AO *(optional)* |
| 7 | brown | **MQ-7 AOUT** → CH0 (via R3/R4) | MQ-7 AOUT |
| 8 | brown-white | **MQ-135 AOUT** → CH1 (via R5/R6) | MQ-135 AOUT |

The heaters get their own pair because they are the only real current (~150 mA each). The
raindrop board at 3.3 V already outputs 0–3.3 V, so CH3 needs no divider. An **LDR** would
need a ninth core: if you fit one, run a second short CAT5e rather than doubling up a
conductor. Cable is cheaper than a debugging trip to the roof.

**Soil cable — 4 of 8 conductors to the vase:**

| Way | Core | Carries | Solder to, at the vase |
|---|---|---|---|
| 1 | orange | **+3.3 V** | DS18B20 red + soil probe VCC |
| 2 | orange-white | GND | DS18B20 black + soil probe GND |
| 3 | blue | **DS18B20 DATA** → GPIO4 | DS18B20 yellow |
| 4 | green | **soil moisture AOUT** → MCP3208 CH2 | soil probe AOUT |

Cut lengths, from the site layout in the CAD (`roofbox_check.py` prints them): **mast
2.4 m · soil 1.4 m · power 0.8 m**, slack and drip loops included.

Both probes sit in the same vase, so one cable is correct — and it keeps soil temperature
and soil moisture describing the same body of soil.

### Where the joints are allowed to be
Every cable has exactly **two** joint locations, and nothing in between:

```
  sensor ──[solder + heatshrink]── CAT5e ──[gland]── screw terminal ── protoboard
           ^                                         ^
           at the sensor, potted                     inside the dry vault
```

- **At the sensor end: solder, then heatshrink.** You have 2 m of 6 mm heatshrink. This
  end is outdoors and gets weather, so it must not be a connector — solder it and seal it.
  Slide the heatshrink on *before* you solder.
- **At the box end: a screw terminal.** This is the one connection meant to be undone, for
  servicing. It lives inside the vault where it's dry.
- **Nothing taped, nowhere.** The masking-tape joints in the bench photo are the fault.

### Strain relief and drip loops — not optional
- **Clamp each cable** with a zip tie on an **adhesive tie mount** bonded to the lid
  underside (positions on sheet 4). Pull on the cable and the tie takes the load, never
  the screw terminal. No holes in the lid for this.
- **Drip loop below every gland**: the cable must go *down* out of the gland and hang below
  it before rising. Water runs to the bottom of the loop and drips off. The glands are
  low in the side wall (§7), 32 mm above the box base, so the loop hangs on the tile.
- Leave ~200 mm of slack inside the box. Tight cabling makes servicing on a roof
  unpleasant and pulls joints apart.

### One thing to check with the multimeter before closing the box
With the mast cable connected and everything running, measure **+5 V at the MQ sensor end
of the cable**, not at the Pi. If it reads below 4.8 V there, the heaters are running cold
and the MQ readings drift — double up pair 1's conductors or shorten the run.

---

## 11. Pi configuration changes

All three are edits on the device; none is optional. **`sudo scripts/pi_config.sh` applies
11.1–11.3 in one go** (`--dry-run` first to see the diff; it backs up `config.txt`), and
`python3 scripts/gate_check.py` confirms them afterwards.

### 11.1 Slow the I2C bus — 400 kHz over unshielded wire is the F2 mechanism
`/boot/firmware/config.txt` currently has `dtparam=i2c_arm_baudrate=400000`. Nothing on
this bus needs 400 kHz; a 60-second log interval is happy at 100 kHz, and the noise
margin roughly quadruples.
```
dtparam=i2c_arm_baudrate=100000
```

### 11.2 Give the OS a real clock (fixes F4)
```
dtoverlay=i2c-rtc,ds3231
```
Then, **and this is the part v0.1 missed** — fit a fresh CR2032/LIR2032 in the DS3231
(the current cell is flat: the chip reads 2000-01-05), and seed it once from NTP:
```bash
sudo hwclock -w          # system (NTP-correct) -> DS3231
sudo hwclock -r          # read back; must show real local time
```
With the overlay loaded, `/dev/rtc0` exists and the kernel restores time at boot *before*
`hics-core` starts — so rows logged during a post-outage, pre-NTP window carry correct
timestamps instead of poisoning the server's dedup key forever.

> Note the ordering hazard: `hics-*.service` already start after `network.target`, but the
> RTC must be read before them. The kernel overlay handles this; the userspace
> `RTC.sync_from_system()` in `sensors/rtc.py` does not and never did.

### 11.3 Resolve the camera overlay conflict (F6)
`config.txt` carries both `camera_auto_detect=1` and `dtoverlay=ov5647`. Keep one. With
the camera physically removed, **comment out `dtoverlay=ov5647`** so the driver stops
retrying a chip that isn't there and filling the log with `i2c read error`. Restore it (or
rely on auto-detect alone) when the camera goes into its own housing.

### 11.4 Interface config that is now wrong for this board
`sensors/config.py` says `INTERNET_IFACE = 'wlan1'` and `HOTSPOT_IFACE = 'wlan0'`. A Pi
3B+ has **one** wlan. There is no `wlan1`, so the `IESH_Hub` hotspot the README describes
does not exist on this unit. For the Lalitpur deployment the station joins home WiFi on
`wlan0` (currently `liverpool08_2.4`, signal 70) and that is sufficient — but the README's
hotspot section does not describe this station and should say so.

---

## 12. Sensor placement, one by one

| Sensor | Where it goes | Why / gotcha |
|---|---|---|
| **DHT22** air T/RH | Mast, inside a **radiation shield**, ≥ 300 mm clear of the box and ≥ 1 m above the roof deck | Non-negotiable. In the box it reads the box; in direct sun it reads the sun. Shield = 4–6 stacked plates with air gaps — cheap plastic plant-pot saucers, inverted and spaced on a bolt, work genuinely well and cost almost nothing. |
| **BMP280** pressure | **Inside**, on the HAT | Pressure equalises through any small opening, so it can stay in the vault — but the vault must not be *perfectly* sealed or thermal swing gives a false offset. One 2 mm hole on the **downward** face, behind a scrap of PTFE tape or foam, is enough. Currently **absent from the I2C bus (`0x76`)** — reconnect it and re-scan; you have no spare, so if it stays dead it needs replacing. |
| **MQ-7** CO, **MQ-135** gas | Mast, in a **downward-facing vented pod** | Must see ambient air, and they self-heat ~350 mW each — in the vault they'd read their own exhaust and cook the Pi. Down-facing vents keep rain out. Stay a **labelled proxy**, not a calibrated measurement (hics-docs G9). |
| **DS18B20** soil T | **Buried in the planter**, 100 mm deep | Waterproof stainless probe version is already suitable. Needs the 4.7 kΩ pull-up. |
| **Capacitive soil moisture** | **Buried in the planter**, blade vertical | Only meaningful *if there is soil* — see the note below. **Pot the top ~25 mm of the board in epoxy or silicone**; the v1.2 boards leave their electronics exposed above the blade and die within weeks outdoors. Re-run `scripts/calibrate_soil.py` in the actual planter soil — the current `SOIL_DRY = 4021` / `SOIL_WET = 1673` came from a different medium. |
| **DS3231** RTC | Inside, on the HAT | **Fit a fresh coin cell.** The one in it is flat (§11.2). |
| **OLED** | Inside, or omit | A classroom feature with no outdoor purpose. Keep it on the sled for bench commissioning; don't cut a window for it. |
| **Pi camera** (all-sky) | **On a printed tower through the hood**, fisheye ring under a lip at the top, board on a ledge just behind it | The tower is the only lid penetration and the camera is deferred (F6) — so **do not cut the lid yet.** When it comes: print `cam_tower` from `docs/cad/roofbox.scad`, test-fit the real fisheye (U2/U3 — `FE_BACK` is found by trial, so print the ledge shimmable), then cut the bore on sheet 4. The lens is the window (§7). |
| **Raindrop ×2** *(unused)* | Mast, plate angled ~30° | Genuinely useful, and rain is the one channel a Kathmandu monsoon story wants. Needs an ADC channel — **CH3 is free**. |
| **LDR ×4** *(unused)* | Mast, facing up | Cheap daylight/cloud proxy, and it pairs with the sky camera later. **CH4 free.** |
| **PIR, ultrasonic, relay, mic, buzzer** | Not in this build | Real parts, no role in a rooftop climate station. The waterproof ultrasonic is interesting later as a **snow-depth or water-level** channel — that is a Himalayan-transect story, not a Lalitpur-rooftop one. |

### The soil question — settled
The concern was that soil sensors are pointless outdoors. They are pointless *without
soil*, and the ADC confirms the probe is currently in air: raw **4021** is precisely the
`SOIL_DRY` calibration point.

**There are planted vases on the roof, so this resolves itself:** put both probes into one
of them and the channels become real. Choose the **largest vase** available — a small pot
dries out and re-wets far faster than ground soil, so a shallow one produces a
spiky, unrepresentative moisture trace. Bury the DS18B20 at ~100 mm and the capacitive
blade vertically alongside it, in the same vase, so soil temperature and soil moisture
describe the same body of soil.

This turns the two dead channels into the richest pair on the station — soil moisture
against rainfall against air temperature is a genuine agronomy dataset, it directly serves
the AIT framing, and it demos far better than a flatlined channel. It also means the
raindrop sensors (mast, way 6) are worth fitting: rain → soil moisture response is the one
relationship on this station that is visible within a single afternoon.

What would not be defensible is leaving a probe in air and logging the number it produces.

---

### CAD, and the one part that needs printing

`docs/cad/roofbox.scad` models the **real container with the real Pi 3B+** (the product
library models a 4B), the HAT, the buck, the camera tower, the hood table, and — at 1:1 —
the whole site: tile, mast with shield and gas pod, vase with probes, junction box and the
three cable runs. It exists to fit-check, place the sensors, argue about distances, and
emit the templates — not to be a production enclosure.

```bash
docs/cad/render.sh                                          # every view + template + checks
openscad -o tower.stl -D 'part="cam_tower"' docs/cad/roofbox.scad   # the one printed part
```

Views: `site` · `service` · `exploded` · `plan` · `mast` · `cam_tower` · `gas_pod` ·
`shield` · `container`; exact 2D sections `section2d` · `tower2d`; 1:1 templates `lid` ·
`drill_wall`. Renders in `docs/cad/renders/`, templates in `docs/cad/templates/`.

**Almost nothing is fabricated.** The scope is a working station, not a production build:

| Part | How |
|---|---|
| Chassis plate | **The actual lid, with nothing drilled.** Standoffs for Pi and buck are **bonded** to its underside (epoxy or neutral-cure silicone on M2.5 brass standoffs); cable ties go on adhesive mounts. Sheet 4 / `templates/roofbox_lid.svg` give the positions. |
| `cam_tower` | **Print this one — later.** It holds the fisheye-to-sensor spacing, the only dimension that needs accuracy, and it is the only thing that ever cuts the lid. |
| Hood | A 198 mm square of aluminium or corrugated plastic on four 20 mm PVC legs standing on the tile — a table over the box. Aperture for the tower. `hood` is the reference geometry. |
| Gas pod | Any small vented tub, open downward, big enough for two 32 × 20 mm MQ modules side by side. `gas_pod` is printable if convenient. |
| Radiation shield | **Five inverted ~100 mm plant-pot saucers on a bolt** with spacers. Works genuinely well. `shield` is printable if preferred. |
| Stand | A 300 mm concrete paving tile. Heavy, flat, off the deck; box and hood legs stand on it, so the whole unit moves as one. |

**Fit is verified numerically, not by eye.** `roofbox_check.py` asserts: no two lid
footprints overlap; everything inside the ±58 mm usable field; stack 44.5 mm in 178 mm;
fisheye lip 6 mm proud of the hood; the 110 mm ribbon reaches (~90 mm path); hood legs
clear the lid; the tower bore is the lid's only through-cut; gland spacing; and it prints
the cable cut lengths. It has already caught a real overlap, a tie mount outside the field
and hood legs 2 mm into the lid.

Three dimensions in the file are marked **ASSUMPTION** and read off photographs. Measure
them before printing `cam_tower`, or it will not fit:

- `FE_RING_D` / `FE_RING_H` — the fisheye's knurled ring, est. Ø23 × 9 mm
- `FE_BACK` — lens rear to sensor front, est. 3 mm. **This is the one to find by trial**;
  clip-on fisheyes expect 2–4 mm off a phone lens. Print the ledge shimmable.
- `BOX_TOP` / `RIM_W` — the container's taper and flange

---

## 13. Shopping list

Everything not already in the inventory — transcribed in
§5.

| Item | Qty | Why | Where |
|---|---|---|---|
| ~~Short thick micro-USB cable~~ | — | ✅ **F1 reported resolved 2026-09-11.** The board, not the Pi, is now the power entry — no micro-USB in the low-voltage path at all | — |
| 5 V / 3 A supply | *optional* | **not needed:** a 5 V 2 A adapter feeds the Pi and a 9 V adapter through the LM2596 at 5.00 V feeds the MQ heaters alone, grounds common — §8.3's split rail from parts on hand. Buy only to simplify to one supply | SLT |
| Hook-up wire, 22 AWG stranded, 3–4 colours | 1 spool ea | you have jumper sets but no bulk wire | SLT |
| ~~Screw terminal blocks~~ | — | ✅ **bought, bill 884** — 6× 3-pin | — |
| ~~Resistors 4.7 kΩ~~ | — | ✅ **bought, bill 884** — 20 off | — |
| ~~Capacitors 100 nF / 1000 µF~~ | — | ✅ **bought, bill 884** — 10 / 2 | — |
| **2×20 female header (or 2× 1×20 strips)** | 1–2 | ✅ **bought, bill 884** — 4 strips. **This was missing from this list and is the one part that blocks the build**: without it, board-to-Pi is a wire bundle, which is fault F2 | SLT |
| PG7 or PG9 cable glands | 3 | sealed entries — drilled in the box **side wall**, low down, never the lid. **PG7 needs a 12.5 mm hole, PG9 15.2 mm** (the *thread*, not the cable). Rubber grommet + neutral-cure silicone is an acceptable substitute | hardware shop |
| Small weatherproof junction box | 1 | houses the mains adapter **outside** the instrument box | electrical shop |
| ~~12 V→5 V buck module (LM2596)~~ | ~₨150–200 | **Not buying — decided 2026-09-13.** The module on hand is an LM2587S boost (U5). The build runs on 5 V adapters only; see `BOARD-BUILD.md` §2. Revisit only if F1 cannot be closed without it | SLT |
| Neutral-cure silicone | 1 tube | **neutral-cure, not acetoxy** — acetoxy silicone corrodes copper and pins | hardware shop |
| M2.5 brass standoffs + screws | 1 set | Pi and buck to the lid underside — **bonded**, not bolted through | SLT |
| Adhesive zip-tie mounts, 19 mm | 4 | cable strain relief on the lid underside, no holes | SLT / hardware |
| Concrete paving tile | 1 | the stand: box and hood legs sit on it. **≈400 mm for the corrected box** — the legs straddle a wider body now | hardware shop |
| 15-pin camera FFC, 300–500 mm | 1 | frees the lid-up constraint entirely (§16.1). **Not stocked at SLT — order online.** Must be a Pi camera cable: 15-pin, 1.0 mm pitch, contacts on *opposite* faces at the two ends | online |
| Aluminium or corrugated-plastic sheet | 1 | the hood plate. **≈250 mm sq for the corrected 170 mm box — buy 300 mm and cut to fit** once the CAD is regenerated | hardware shop |
| Plant-pot saucers ~100 mm | 5 | radiation shield plates | any nursery |
| — | — | *planter not needed: the roof already has planted vases* | — |
| **CR2032 / LIR2032** | 1 | the DS3231's cell is flat — **§14 gate 2 is blocked without it.** **Not stocked at SLT**; any general shop has them | any |
| 20 mm PVC pipe + clamps | **~3 m** | 1.5 m sensor mast + 4 hood legs. **Legs ≈280 mm, not 220** — the box is 230 mm tall, not 180. Buy long and cut | hardware shop |
| Desiccant sachets | 2–3 | condensation inside the vault | any |
| Epoxy or potting compound | small | pot the soil probe's exposed top | hardware shop |

---

## 14. Build order

Each step is gated: don't proceed while the previous one fails. The gates exist because
F2's symptoms are intermittent, and an intermittent fault found *after* the box is closed
costs a rooftop trip.

1. **Fix power. Verify `vcgencmd get_throttled` reads `0x0`** and stays there for an hour
   with both MQ heaters running. *Nothing below is meaningful until this passes.*
2. **Apply the `config.txt` changes** — `sudo scripts/pi_config.sh` (§11.1–11.3) — fit the
   DS3231 coin cell, reboot, `sudo hwclock -w`, confirm `hwclock -r` reads correct local
   time and `/dev/rtc0` exists. `python3 scripts/gate_check.py` checks G2/G3.
3. **Rework the protoboard** (§9). Keep the soldered MCP3208; cut out the jumper-to-jumper
   chains; add R1–R6, C1, C2; fit the screw terminals. Work from the
   [placement sheet](docs/drawings/perfboard.svg) and the
   [schematic](docs/drawings/schematic.svg). Do the Pi header, ground strip and 3.3 V/5 V
   distribution first; **continuity-check every net with the multimeter before fitting any
   IC or plugging it onto the Pi.** A shorted rail on a soldered board is much less
   forgiving than on a breadboard.
4. **Restart the services** — `sudo systemctl restart hics-core hics-web` — so the fixed
   firmware from §4 is finally the code that runs. Confirm the log shows
   `Logged to DB (… rows)` with a `| NULL:` note naming exactly the channels you know are
   disconnected. **That note appearing is the gate**: it is the freshness/plausibility
   gating doing its job, and its absence means you are still running v0.1.
   `gate_check.py` G6 reads it for you.
5. **Bring up one sensor at a time on the bench**, HAT on the Pi, running
   `python3 tests/test_all.py --skip camera` after each (or `--only bmp280,oled,rtc` for
   the trio). Order: I2C trio (BMP280 / OLED / DS3231) → MCP3208 + soil → DS18B20 → DHT22
   → MQ pair. Adding them one at a time is what makes an intermittent fault attributable.
6. **Run 24 h on the bench.** Gate: `sqlite3 ~/hics-data/hics.db "SELECT date(timestamp),
   COUNT(*) FROM telemetry GROUP BY 1"` shows **~1440 rows** for a full day, and
   `get_throttled` is still `0x0`. This directly closes F5 — the station has never yet
   done this.
7. **Bond the standoffs to the lid** (sheet 4), fit the stack, **drill the three gland
   holes and the vent in one side wall** (`templates/roofbox_drill_wall.svg`, 1:1), fit
   the glands, seal. Silicone needs 24 h to cure. The lid itself gets no holes.
8. **Assemble the mast**, radiation shield and gas pod; wire to the terminals.
9. **Deploy to the roof.** Box inverted, off the deck, shaded if possible. Drip loops on
   every cable *below* the gland.
10. **Re-register the station public** on the website only after 48 h of clean data (§15).

---

## 15. Website — before going public again

The station is deliberately not in the public list right now (`/api/v1/stations/` returns
`[]`, `status` outside `active`/`maintenance`); it goes back after this round of work.
Two things to do first, both in `../../himalayansciences-web`:

**Purge the existing readings for `IESH-KMC-001`.** The garbage from F3 is already stored
server-side — the live API returns `pressure_hpa: 0.0` — and because ingest is
`get_or_create` on `(station, timestamp)`, re-POSTing corrected rows will **not** overwrite
them. Starting the public series clean is the only honest option.
⚠️ **Destructive, and it is a decision, not a step — confirm before running.**

**Then set `status = 'active'`** so it appears in the public list and on the map.

Worth knowing and leaving alone: every reading is stamped `quality_flag = 'suspect'`
because the server flags any `v0.*` firmware that way, regardless of value. That is correct
and intended for a prototype — uncalibrated sensors, an MQ proxy, unverifiable timestamps
(hics-docs G9). Do not bump `FIRMWARE_VERSION` past `v0.` to make the flag go away; it
should only move when the data is genuinely calibration-grade.

---

## 16. The rethink — what to question rather than inherit

This is the part worth reading. Everything above is defensible; some of it is only
defensible *given constraints that a small purchase would remove*.

### 16.1 The camera ribbon is driving the entire enclosure design. Buy a longer one.
The ribbon on hand is **110 mm**. That single fact forced: camera in the lid → lid must
face up → rain can sit on the gasket → a hood becomes mandatory → glands must move to the
side wall. **Lid-*down* is strictly better weatherproofing** (every penetration faces the
ground, gravity loads the seal correctly), and it was rejected only because the Pi would
then sit 180 mm from the sky-facing end.

**A 300–500 mm 15-pin FFC costs almost nothing.** Buy it, then revisit the orientation
from scratch. Do not inherit lid-up as though it were a design decision; it is a
workaround. (The tower of §16.8 makes lid-up *work*; a long ribbon would make it
*unnecessary*.)

### 16.2 Question the container itself before designing further around it
A food container is a genuinely defensible proof-of-concept housing, and "we built it with
what we had" is an honest story. But a proper **IP65 ABS junction box** is cheap in
Kathmandu, arrives with a real gasket, moulded gland bosses and mounting lugs, needs no
hood improvisation — and will photograph far better for Swiss Week. Spend thirty minutes
pricing one at Supreme Light Technology (Sanepa-2) before committing. If the container
wins on cost or timing, fine — but make it a decision, not a default.

Related: **five container dimensions in `roofbox.scad` are estimates read off photographs**
(§5). Measure before printing anything.

### 16.3 The perfboard drawing is deliberately incomplete, and you should finish it differently
`perfboard.svg` is a **zoned placement** drawing, not a hole-exact route. That was a
judgement call: the physical board already has the MCP3208 and its power lines soldered,
and authoring a hole-by-hole route without that board in hand produces a drawing that is
wrong in detail *and trusted anyway* — the worst outcome.

**The right way to finish it:** photograph the existing board top and bottom, count the
actual occupied holes, and *then* extend `scripts/gen_drawings.py` with the real routing.
The generator is structured for this — `ZONES` is already data.

### 16.4 Do not build on a sagging rail, and do not trust "it worked before"
F1 is live. "It worked fine on the power bank at the AIT pitch" and "the Pi reports
under-voltage" are **both true simultaneously** — the Pi runs while throttled, and marginal
peripherals drop off. That *is* F2. Order of attack:

1. **Short thick micro-USB cable** (≤ 1 m, 20 AWG). Often the entire answer; a thin lead
   drops 0.5 V+ at 2 A regardless of the brick's rating.
2. A genuine **5 V/3 A** supply — not a power bank.
3. **Feed the MQ heaters from their own 5 V rail**, not through the Pi. Two heaters are
   ~300–400 mA of switching load, which is what tips a marginal supply over.

Then measure with the multimeter you already have: **GPIO pin 2 or 4 (+5 V) to pin 6 (GND)**,
under load. Below 4.75 V is the fault.

### 16.5 Mains is now going to the roof — keep it out of the instrument box
A wall-socket line is being run up. That settles the topology, but **no 240 V inside a
plastic food container on a roof.** Adapter in its own small junction box; only low voltage
crosses the gland. Prefer **12 V + a small buck module** over 5 V if the adapter ends up
more than about a metre away — 12 V draws ~2.4× less current for the same power, so the run
loses far less voltage, and voltage drop *is* F1. Keep the lead-acid UPS **indoors**: heat
kills lead-acid, and a hot roof is the worst place for it.

### 16.6 What actually earns a render, and what doesn't
A 3D render of a food container told us almost nothing we didn't already know — that steer
was correct. What paid off was the **2D schematic** (it caught nothing, but it is what you
solder from) and, unexpectedly, the **numeric checks**: an XY clash test caught a real
camera-over-Pi overlap that two rounds of eyeballing renders had missed, and a unit test
caught a bug in the frozen-register gate that looked right in code review.

**Generalise that.** Prefer a computed assertion over a picture. Reserve renders for the
pitch deck, where communication is the actual job, and for verifying that a *mechanism* is
what you think it is.

The second pass confirmed it twice more: the unit test that "caught a bug in the frozen
gate" had itself enshrined a wrong rule (a steady sensor is not a frozen one — §4), and
`roofbox_check.py` caught three placement errors that the renders showed and nobody saw.
And OpenSCAD 2021's *preview* paints cut faces flat over hollows, so 3D section renders
were quietly lying; the sections are now exact 2D projections instead (§19).

### 16.8 What the audit changed in the enclosure, and why
Four things in the first CAD draft would have been built wrong:

1. **The hood blinded the camera.** A fisheye flush in the lid under a 32 mm hood with a
   49 mm aperture sees a ~75° cone. Now a printed **tower** carries the lens up through
   the hood, 6 mm proud of it.
2. **Hood legs bolted through the lid at ±65 mm — on the gasket channel.** The hood is
   now a **free-standing table** on the paving tile; nothing bolts to the lid.
3. **The lid had ~20 holes, all facing the sky**: hood legs, six zip-tie slots, eight
   standoff screws. Now: standoffs **bonded**, ties on **adhesive mounts**, and the only
   penetration is the tower bore — which waits for the camera. **Today the lid is not
   drilled at all.**
4. **`GLAND_ID = 7` was the cable size, not the hole.** A PG7 gland needs a **12.5 mm**
   hole. It would have been drilled at 7.
5. The fisheye seat was a cup open to the sky — a water trap. The ring now goes in from
   inside under a 2 mm **lip**, bedded in silicone.

### 16.7 Scope honestly: this is a robust DIY build, not a production one
The two routed PCBs (`carrier-hat-v1`, `power-mgmt-v1`) and the printed EDU/SCI enclosures
already exist in `../iesh-production-reference/` and **are** the product. This deployment is
the working proof that logs real data. Show both at Swiss Week; don't let a render imply the
container is the product, or the container imply the renders are vapour.

---

## 17. ⚠ UNVERIFIED — measure or confirm before relying on any of these

| # | Assumption | Where | How to settle it |
|---|---|---|---|
| U1 | `RIM_W = 8`, `RIM_T = 6`, `BOX_WALL = 1.8` | `roofbox.scad` | Calipers. **The body is now measured: 130 base / 170 top / 230 tall, internal (§5) — the CAD still has the old 120 × 120 × 180 and must be corrected.** Rim and wall remain estimates |
| U2 | `FE_RING_D = 23`, `FE_RING_H = 9` — the fisheye's knurled ring | `roofbox.scad` | Calipers, before printing `cam_tower` |
| U3 | `FE_BACK = 3` — fisheye rear to sensor front | `roofbox.scad` | **Trial and error.** Clip-on phone fisheyes expect 2–4 mm off a phone lens. Print the seat shimmable |
| ~~U4~~ | ~~The 30 resistors on bill 724 include 4.7 kΩ~~ | — | **Closed 2026-09-11** by buying 20 known 4k7 (bill 884). Still meter them and match the MQ pairs |
| U5 | The ₨650 "boom/boost module" | — | **Re-opened 2026-09-13: chip is `LM2587S`, a BOOST.** The 2026-09-11 "LM2596 buck" closure was wrong — it was never measured. Buy a real LM2596 |
| U6 | DHT22 breakout already carries its own pull-up | schematic R2 | Inspect the module before adding a second |
| U7 | BMP280 is merely disconnected, not dead | §2 | Reconnect and re-scan `0x76`. **There is no spare** — if dead it needs buying |
| U8 | `PSU`/`BUCK` module dimensions in the CAD | `roofbox.scad` | Measure the actual module — the buck to be bought (U5 — the module on hand is an LM2587S boost) |
| U9 | Whether the new firmware behaves correctly on real hardware | §4 | **It has not run yet.** Restart the services and watch the log; `gate_check.py` G6 |
| U10 | Tower ledge / ribbon fold geometry (`TOWER_IX/IY`, `LIP_T`, ledge width) | `roofbox.scad` | Only meaningful once the camera board and fisheye are in hand. Print one, test-fit, adjust |
| U11 | The buck module is 25 × 45 × 16 and mounts on M2 standoffs | `roofbox.scad` (U8) | Measure the module on bill 745 (U5) — the lid layout moves if it is bigger |
| U12 | The container lid accepts bonded standoffs (PP surface) | §12 | Scuff + epoxy on a test patch first; PP is a poor glue surface. Fallback: through-bolt with sealed heads |

---

## 18. Open decisions — not for an agent to make alone

1. **Purge the existing website readings for `IESH-KMC-001`?** The F3 garbage is already
   stored server-side (the live API returns `pressure_hpa: 0.0`), and because ingest is
   `get_or_create` on `(station, timestamp)`, re-POSTing corrected rows **will not**
   overwrite them. Starting the public series clean looks like the only honest option — but
   it is **destructive and irreversible. Confirm with Pawan before running anything.**
2. **`git init` the `iesh-production-reference` folder?** See §6 — the roofbox CAD no longer depends on it, but the product CAD there is still unversioned.
3. **Container or IP65 junction box?** See §16.2.
4. **Buy the longer camera ribbon and redo the orientation?** See §16.1.
5. **Bump `FIRMWARE_VERSION` past `v0.`?** **No — leave it.** The server flags every `v0.*`
   reading `suspect` deliberately: uncalibrated sensors, an MQ proxy, unverifiable
   timestamps (`hics-docs` G9). It should move only when the data is genuinely
   calibration-grade. Do not "fix" the suspect flag.

---

## 19. Things that will waste your time if you don't know them

- **`deploy.sh --restart` cannot restart the services** — the `sudo` step needs a TTY
  password. Sync works; the restart must be run by hand on the Pi.
- **`sensors/config.py` is never synced** by `deploy.sh` (it holds the API key) and is
  `--assume-unchanged` on the Pi. The local copy has `API_KEY = ''`; the device's is set.
- **`i2cdetect` is not installed** on the station. Scan with `smbus2` from Python instead —
  there is a working snippet in this session's history, or just loop `read_byte`/`write_quick`.
- **`sudo` needs a password** for everything on the station.
- **ImageMagick silently ignores `fill-opacity`** on `<rect>` and cannot parse quoted
  multi-family `font-family` stacks. `gen_drawings.py` works around both — don't
  "modernise" the fonts or the tint helper without re-rasterising to check.
- **OpenSCAD's PNG backend ignores alpha**, so a transparent shell renders opaque and hides
  everything. That's why `roofbox.scad` has `exploded` and `section` views rather than one
  transparent assembly.
- **The `else if` chain in `roofbox.scad` used to fall through to `assembly()`** — five
  parts once "compiled fine" while actually rendering the assembly. It now ends in
  `assert(false, "unknown part")`, so a typo fails loudly.
- **OpenSCAD 2021's preview cannot be trusted for section views**: on a nested cut it
  paints the cut face flat across hollows (verified: the STL volume of the half-tower is
  exactly half the hollow tower, yet every preview showed it solid). `render.sh` therefore
  emits sections as exact 2D `projection(cut=true)` SVGs. Trust `roofbox_check.py` over
  any picture.
- **STL-exporting the `site` assembly takes minutes** (CGAL on the whole roof). Preview
  PNGs are seconds. `render.sh` only exports STL for small parts.
- **`quality_flag = 'suspect'` on every reading is correct**, not a bug. See §18.5.

---

## 20. What this deployment does *not* claim

Written down so the Swiss Week material doesn't overstate it.

- **It is not calibrated.** MQ-7 and MQ-135 are labelled proxies; soil moisture is a
  relative index against a two-point calibration. `quality_flag` says `suspect` and that
  is accurate.
- **It is one station, on one rooftop, at 1350 m.** The 4000 m validation environment in
  the AIT pitch is an argument about *where HICS can work*, not a place data has come from.
- **The interim enclosure is a food container.** That is a deliberate, honest
  proof-of-concept step — the printed EDU/SCI enclosures and the two routed PCBs in
  `../iesh-production-reference/` are the product, and they exist. Show both; don't let a
  render imply the container is the product, or the container imply the renders are vapour.
- **No all-sky camera data yet.** Deferred this round (F6, §2).

---

*Diagnosis, firmware fixes and drawings: 2026-09-03, from a live session against
`iesh.local`; audited, corrected and extended the same evening (§4 second pass, §16.8).
Firmware is committed and tested (23 checks). **The hardware rebuild is not started** —
the circuit is part-disassembled on the bench and the camera is out. Next session starts
at `docs/README.md`, then §14 step 1 with the multimeter.*

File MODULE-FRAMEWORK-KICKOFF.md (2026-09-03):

# Kickoff — IESH firmware Module framework (plug-and-play sensors)

Self-contained brief for a **fresh, independent session**. This is **pure software** in this
repo (`hics-iesh-v0.1`) — it needs no hardware and runs in parallel with the PCB/enclosure
work. Background memory auto-loads; also read `../iesh-production-reference/05-modular-platform/`
(the architecture) and that repo's `02-pcb/carrier-hat-v1/` (the connector this targets).

## Goal
Turn the v0.1 hardcoded per-sensor drivers into a **Module framework**: a sensor module plugs
into the Carrier HAT's **MODBUS connector**, firmware **auto-detects** it, loads its driver,
logs it, shows it on the OLED + web dashboard, and teaches with it — **no rewiring, no reflash**.
This is what makes "add a new sensor" a small driver instead of edits across the codebase.

## Where things are today (v0.1)
- `sensors/` — one module per sensor (`dht22.py`, `bmp280_sensor.py`, `mcp3208.py`,
  `air_quality.py`, `ds18b20.py`, `rtc.py`, `oled.py`, `camera.py`), each with an ad-hoc API
  and an `.ok` flag. `sensors/config.py` is the hardware map (pins/addresses/calibration).
- `core_dash.py` — the sensor loop: reads each sensor, renders OLED, logs to SQLite.
- `data/database.py` — `telemetry` table (fixed columns), `data/uploader.py` — cloud sync.
- `web/app.py` — dashboard; `curriculum/modules/*.py` — activities bound to sensor values.

## The hardware contract it targets (frozen)
From `../iesh-production-reference/02-pcb/carrier-hat-v1/docs/DESIGN.md`:
- **MODBUS v1** connector: 5V, 3V3, I²C (SDA/SCL), UART, SPI, 2 spare ADC (CH3/CH4),
  **DETECT/ID**, ENABLE, IRQ. Plus a dedicated PMS5003 UART slot.
- **I²C address map (reserved):** SHT4x 0x44, SCD40 0x62, ADS1115 0x48 — discovery can probe these.
- **DETECT line:** a resistor-code (or ID EEPROM later) identifies a module type cheaply.

## Build this (suggested order)
1. **`Module` interface** (an ABC), per `05-modular-platform/00-architecture.md`:
   `identity()` → {type, revision, logical_channels, track} · `present()` → bool ·
   `read()` → {channel: value} · `calibration()` → {status, date, params}.
2. **Module registry + discovery at boot:** probe known I²C addresses + read the DETECT
   resistor-code → instantiate the matching `Module`. Fall back to the built-in base sensors.
3. **Refactor the existing sensors** to implement `Module` (keep `config.py` values identical
   so behavior is unchanged — the PCB preserves the v0.1 pin/divider/RL values on purpose).
4. **Logical channels:** modules declare names (`pm2_5`, `co2_ppm`, `air_temp`, …); make the
   data model, OLED, dashboard, and curriculum **bind to channel names**, not fixed columns
   (so a new module's data flows end-to-end without schema edits). Add a `modules`/discovery
   record + a per-module calibration record.
5. **Wire it through:** `core_dash.py` iterates discovered modules; `database.py` stores by
   channel (consider a long/EAV table or JSON column); `uploader.py` sends channel-keyed
   batches (note: real API is `POST /api/v1/ingest/environmental/`, `Authorization: Token`,
   `{station_id, readings:[…]}` — see the himalayansciences-web repo).
6. **A driver template** others copy to add a module (mirrors the KiCad module template).

## Verify
Run the loop on dev (sensors stubbed/mocked) — discovery picks up "present" modules, logs
channel-keyed data, dashboard renders them. Then on real hardware, plug an SHT4x/SCD40 and
confirm it auto-appears. Don't break the existing base sensors (regression-test `tests/`).

## Independence
No dependency on the PCB/enclosure being finished — the connector pinout + address map above
are frozen. Ship the framework; real modules (PMS5003/SCD40) get built in parallel on the HW side.

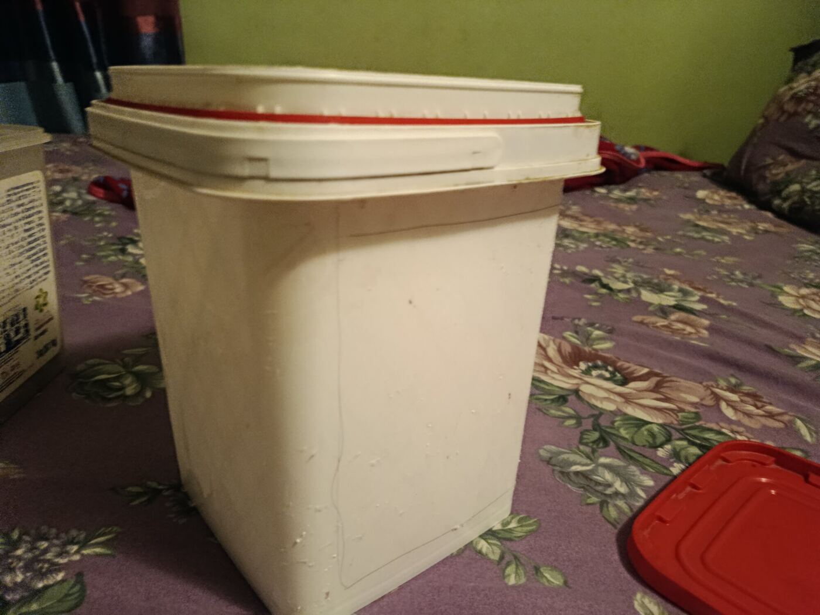
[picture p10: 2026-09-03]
docs/reference-photos/02-container-exterior.jpg

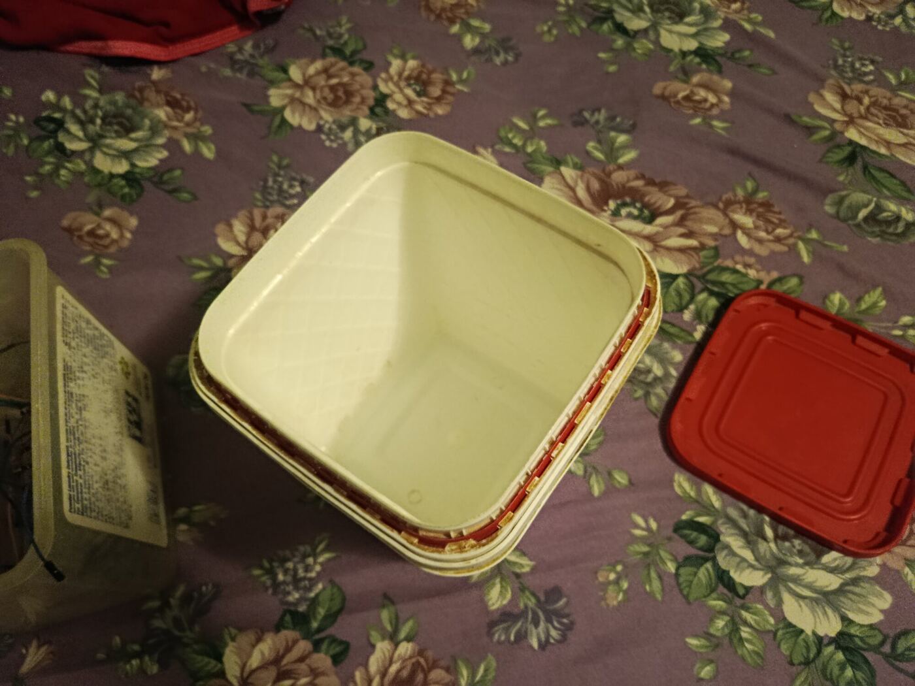
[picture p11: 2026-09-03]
docs/reference-photos/03-container-interior-gasket.jpg

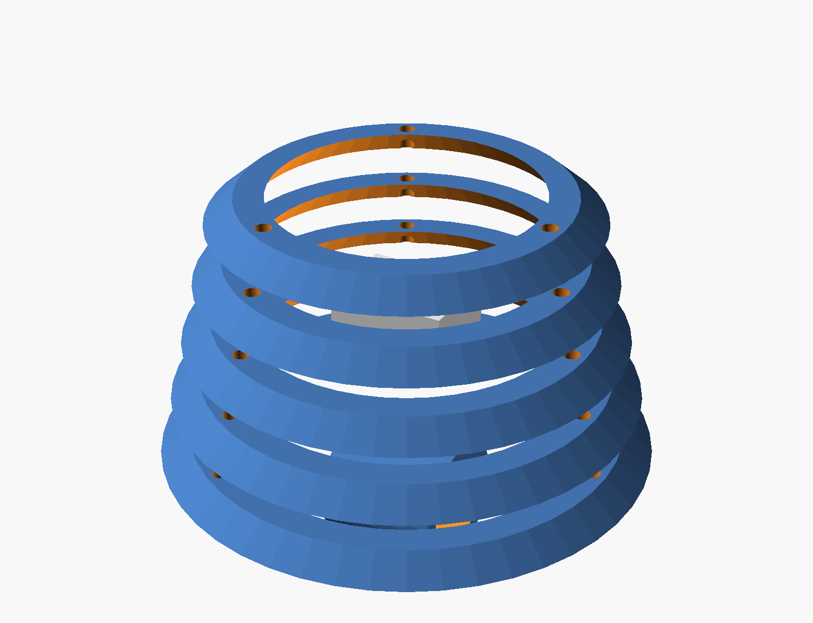
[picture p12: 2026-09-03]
docs/cad/renders/shield.png

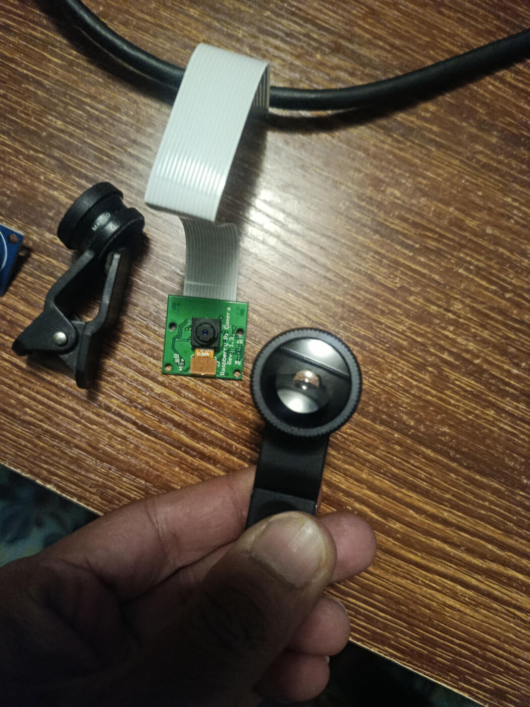
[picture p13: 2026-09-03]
docs/reference-photos/04-camera-and-clipon-fisheye.jpg

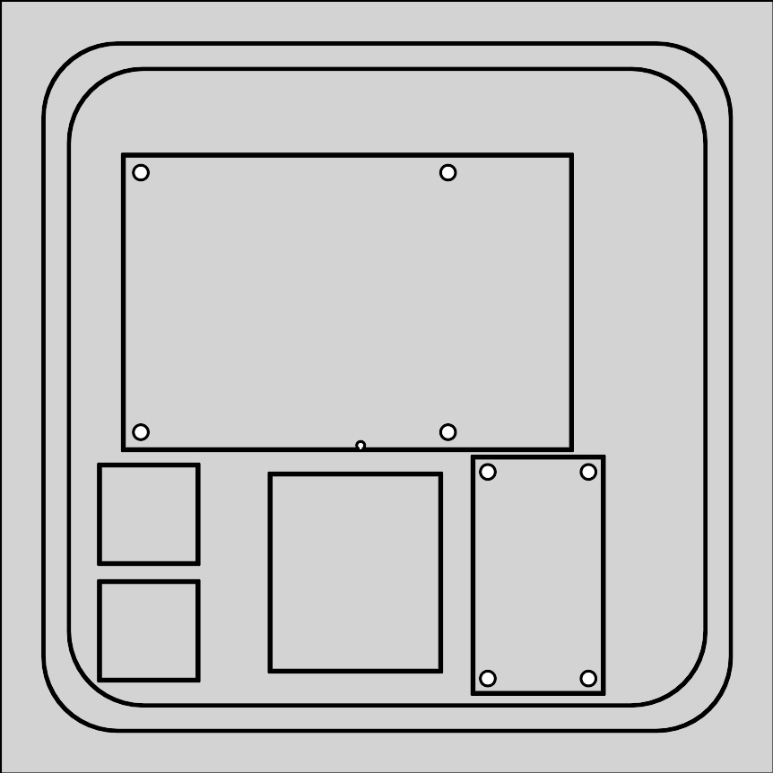
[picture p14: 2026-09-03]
docs/cad/renders/lid.png

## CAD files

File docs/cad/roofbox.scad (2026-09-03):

// ============================================================================
// IESH-ROOFBOX — interim rooftop variant, Lalitpur proof-of-concept
//
//   The enclosure is a FOUND OBJECT: a 120 x 120 x 180 mm gasketed square food
//   container with a snap lid (red silicone seal). It is not printed and not the
//   product — the printed EDU/SCI shells in edu.scad / sci.scad remain that.
//   SCOPE: a working deployment, not a production build. So almost nothing here
//   is fabricated — the real lid is a placement job (see lid_layout()), the gas
//   pod can be any small vented tub, and the radiation shield can be five
//   inverted plant-pot saucers on a bolt. The ONE part that genuinely wants
//   printing is cam_tower(), because the fisheye-to-sensor spacing has to be
//   held accurately. Everything else is a found object.
//
//   This file exists to (a) fit-check the real electronics in the real
//   container, (b) place the sensors, and (c) emit the drilling template.
//
//   Product tier: powered outdoor site (home / school roof), i.e. tier 2 in
//   01-hardware/04-power-architecture.md -> closer to CONFIG-SCI-BUILDING than
//   to CONFIG-EDU-BASE. No display window, no demonstrative cutaway.
//
//   THE CENTRAL DECISION: the LID IS THE CHASSIS PLATE. Everything bolts to it;
//   the box body is just a cover that closes over the assembly onto the gasket.
//   Lid off = the whole instrument lifts out as a unit for bench work, and
//   nothing is ever assembled inside a 120 mm box.
//
//   ORIENTATION: LID UP, and this is forced by the camera, not chosen.
//   The Pi camera ribbon on hand is only 100-120 mm. An all-sky camera must
//   look up; the Pi must be within a ribbon's length of it. So the camera sits
//   in the lid and the Pi hangs directly beneath it — about 60 mm of ribbon.
//   Inverting the box (lid down) would put the Pi 180 mm from the sky-facing
//   end and the ribbon would not reach. Buying a 300-500 mm FFC would free the
//   choice; with this ribbon, lid-up is the only layout that works.
//
//   The cost of lid-up is that rain can sit on the lid gasket, so the hood()
//   part is NOT optional — it keeps direct rain off the seal. It is needed for
//   solar-gain reasons anyway (a sealed box in Kathmandu sun runs 45-55 C
//   inside), so one part solves both problems.
//
//   Cable glands therefore move OFF the lid and into the box side wall, low
//   down, so no penetration faces the sky. Drip loops below each one.
//
//   Environmental sensors do NOT live in here. A sealed box on a Kathmandu roof
//   runs 45-55 C inside; a DHT22 in it measures the box. See gas_pod() and
//   rad_shield() for where they go, and ../../HANDOFF.md §7 / §12.
//
//   LIVES IN hics-iesh-v0.1/docs/cad/ (versioned with the deployment it serves),
//   not beside edu.scad/sci.scad in iesh-production-reference - those are the
//   product; this is one rooftop. ./render.sh regenerates every view below
//   into renders/ and templates/, and runs roofbox_check.py.
//
//   THE CAMERA MUST CLEAR THE HOOD. The first draft seated the fisheye flush in
//   the lid, under a 32 mm-high hood with a 49 mm aperture: an "all-sky" camera
//   that could see a 75 degree cone. cam_tower() now carries the lens up THROUGH
//   the hood so it sits proud of it and sees the whole hemisphere. The ribbon
//   still reaches: the tower sits directly under the Pi's CSI connector.
//
//   THE LID GETS NO HOLES IT DOES NOT NEED. Second-pass audit: the first draft
//   bolted the hood legs through the lid at +/-65 mm - on the gasket channel -
//   and put six zip-tie slots through it. Now: the hood is a free-standing
//   table over the box (legs to the paving tile, not the lid); cable ties go
//   on adhesive mounts; Pi and buck standoffs are BONDED to the lid underside.
//   The only lid penetration is the camera tower, and the camera is deferred -
//   so today's build drills the lid NOWHERE. lid_layout() is a placement
//   template, not a drilling template.
//
//   THE LENS SITS UNDER A LIP, NOT IN A CUP. A pocket facing the sky is a water
//   trap; the ring now goes in from inside the tube and beds in silicone under a
//   2 mm lip, so the lip sheds water and the silicone is never the first line.
//
//   Section views are 2D (projection(cut=true)) because OpenSCAD 2021's preview
//   cannot be trusted to show a nested cut - it paints cut faces flat. The 2D
//   sections are exact; roofbox_check.py measures what a picture cannot.
//
//   render:  part = "site"      the whole station on the roof: box, mast, vase, cables
//                 | "service"   the box as it stands: hood table, tower, body
//                 | "exploded"  hood plate / plate stack / body, pulled apart
//                 | "plan"      plate layout from the interior side
//                 | "mast"      shield + gas pod + rain plate on the PVC
//                 | "chassis" | "cam_tower" | "hood" | "gas_pod" | "shield" | "container"
//            2D:  | "section2d"  service orientation, cut on the tower's centre plane
//                 | "tower2d"    the tower alone, same cut
//                 | "lid"        1:1 lid PLACEMENT template (bond standoffs; witness only)
//                 | "drill_wall" 1:1 side-wall template: 3 gland holes + vent
//   check:   python3 roofbox_check.py     (XY clash, field, height, sky, ribbon, cable lengths)
// ============================================================================

part = "assembly";
$fn = 48;

// ---- the found container ---------------------------------------------------
// MEASURED: 120 x 120 base, 180 tall (excluding the rim).
// ASSUMPTION: the taper and the rim flange are estimated from photographs.
// TODO: measure BOX_TOP and RIM_W with calipers and correct these two lines.
BOX_BASE   = 120.0;   // outer, at the closed (moulded) end
BOX_TOP    = 130.0;   // ASSUMPTION - outer, at the lid opening
BOX_H      = 180.0;   // excluding rim
RIM_W      = 8.0;     // ASSUMPTION - flange width beyond BOX_TOP
RIM_T      = 6.0;     // ASSUMPTION - flange thickness
BOX_WALL   = 1.8;     // ASSUMPTION - typical PP food container
BOX_R      = 14.0;    // corner radius
GASKET_T   = 2.0;     // red silicone seal in the lid channel

LID_T      = 2.5;     // lid panel thickness
LID_W      = BOX_TOP + 2*RIM_W;

// Interior clear space, at the lid end (the widest point, where we mount).
IN_AT_LID  = BOX_TOP - 2*BOX_WALL;      // ~126
USABLE     = IN_AT_LID - 10;            // ~116 - keep clear of the seal channel

// ---- real electronics ------------------------------------------------------
// Raspberry Pi 3B+ (this station), NOT the 4B modelled in iesh_lib.scad.
PI_W = 85.0;  PI_D = 56.0;  PI_T = 1.6;
PI_MH = [[3.5,3.5],[3.5,52.5],[61.5,3.5],[61.5,52.5]];   // M2.5, 58 x 49 grid
PI_PORTS_H = 17.0;                       // USB/Ethernet stack

// Protoboard HAT — 10 x 15 cm matrix board cut to the carrier-hat-v1 footprint,
// so the layout transfers when 02-pcb/carrier-hat-v1 is fabbed.
HAT_W = 65.0;  HAT_D = 70.0;  HAT_T = 1.6;

STANDOFF_LID = 10.0;                     // lid inner face -> Pi PCB bottom
SOCKET_GAP   = 12.8;                     // Pi top -> HAT bottom (40-pin socket)

Z_PI   = LID_T + STANDOFF_LID;
Z_HAT  = Z_PI + PI_T + SOCKET_GAP;

// POWER: a 12 V -> 5 V 3 A buck module, NOT a mains adapter.
// Three reasons this is the right call for a rooftop box:
//   1. no mains inside a plastic food container on a roof;
//   2. 12 V up the cable draws ~2.4x less current than 5 V for the same power,
//      so the run loses far less voltage — and voltage drop IS fault F1;
//   3. it feeds straight off the 12 V lead-acid UPS with no double conversion.
// The 5 V adapter stays indoors, or is replaced by the UPS entirely.
BUCK_W = 25; BUCK_D = 45; BUCK_H = 16;   // ASSUMPTION - measure yours (U8).
                                         // Mounted long side along Y.
Z_BUCK = LID_T + 6;                      // its own short standoffs
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

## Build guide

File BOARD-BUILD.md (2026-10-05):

# Board build — working doc

Live bench notes for the IESH v0.2 HAT, built **2026-09-11 onward**. This is the sheet you
work from at the desk. Narrative, faults and the wider build order stay in
[`HANDOFF.md`](HANDOFF.md); the generated sheets stay in [`docs/`](docs/README.md). Anything
decided here that changes a documented fact gets folded back into `HANDOFF.md`.

---

## ▶ NEXT SESSION — start here

*Written 2026-10-05 for the next bench session.*

**The plan changed on 2026-10-05.** Read `HANDOFF.md` §0.1 and
[`docs/rooftop-plan.html`](docs/rooftop-plan.html) (rev 6) first. The board stays as built.
What changes is the **terminal plan** (step 7 below replaces the old 14-way mast/soil/power
plan) and the **dew-heater pads**. ⚠ The Tools Competition abstract is due 13 Oct ET, with
submission targeted for 10 Oct. Keep station sessions bounded this week.

**State, verified:**
- Header, three rails, MCP3208 and ADC gate all pass (2026-09-12/13).
- The Pi is powered through GPIO: 5 V 2 A adapter → `(47,W)` → pins 2/4, 1000 µF at the feed.
- CR2032 reads 3.2 V.
- **Camera + fisheye work (2026-10-05).**

**Still open:** F1, which undervolts under sustained 4-core load. Power stays as built (no buck);
it is managed in software (session step 5).

### The session, in order

| # | Do | Gate before moving on |
|---|---|---|
| 1 | **Paper-strip ribbon test** (10 min). Pi + board against the box's inside wall, **USB/Ethernet end up**, under the lid. Route a 110 mm × 16 mm paper strip from the camera connector, under the board, out at the A-edge, past the USB jacks, to the lid. Mark the tower position | Reaches with ≥5 mm spare → keep the 110 mm ribbon. Otherwise → the 30 cm ribbon (Himalayan Solution). **Doesn't block soldering** |
| 2 | **1d — meter the passives.** 4.7 kΩ: two matched pairs (R3/R4, R5/R6) plus R1, R2 and the LDR divider. From bill 724's unlabelled 30: find **8 × 220–330 Ω** for the dew heater | Values written on the bag |
| 3 | **Step 6 components** (list below) | Board OFF the Pi. The three rails still open to each other; every new net buzzed against sheet 1; no CH pad shorted to a rail |
| 4 | **Step 7 terminals**: 20 ways from the new map below. **Label every way in pen** | Each way buzzed to its destination pad |
| 5 | **On the Pi.** `sudo scripts/pi_config.sh --dry-run` → apply → `sudo systemctl disable hciuart` → reboot. Fit the CR2032 → `sudo hwclock -w && sudo hwclock -r`. Then `sudo systemctl restart hics-core hics-web` and `python3 scripts/gate_check.py` | `/dev/rtc0` exists, the clock reads true, and the log shows the `\| NULL:` note |
| 6 | **Power under camera load**: `rpicam-vid -t 0 -n --width 640 --height 480 --framerate 5 -o /dev/null` running, check `vcgencmd get_throttled` over an hour | `0x0`. If not: swap the two 5 V sources → retest → the sky pipeline by day only. The LM2596 is the last rung, not bought |
| 7 | **Sensors one at a time** (step 8): I2C trio → soil → DS18B20 → DHT22 → MQ pair → raindrop (CH3) → LDR (CH4). `python3 tests/test_all.py --skip camera` after each | Each one reads plausibly before the next goes on |

**On the bench:** meter, iron, 4.7 kΩ, 220–330 Ω, 1000 µF, 8 × 3-way terminals, the plastic
box (for step 1), paper and scissors, indelible pen, CAT5e offcut.

### Firmware for Claude to do in parallel
Steps 1–4 are hands-on. These need no hardware and can be written meanwhile:
- `sensors/config.py`: `CH_RAIN = 3`, `CH_LDR = 4`. `core_dash.py`: read both through the
  `ChannelSet` health gate. Decide new DB columns vs the ingest's `module_data` blob, which
  is the extension point (HANDOFF §1.4).
- Health channels: Pi CPU temperature and `get_throttled` bits, logged with each row, so
  readings taken under undervoltage are flagged rather than silently trusted.
- `INTERNET_IFACE` (HANDOFF §11.4): the 3B+ has only `wlan0`.
- Tests for all of the above, in `tests/test_health.py` style.

---

## 0. What is being built, and on what

A fresh board. **The old demo board is not reworked** — bill 884 bought a second MCP3208, so
the old one is set aside intact as a reference and parts donor. No desoldering, no island
cutting, no risk to a part there is only one of.

| | |
|---|---|
| Board | blank `PY-10CM*15CM`, **150 × 100 mm**, **uncut** |
| Grid | **48 columns × 36 rows**, 2.54 mm (= 122 × 91 mm; the missing ~28 mm is the two oval-pad strips at the ends) |
| Oval edge pads | **isolated — metered 2026-09-11, no continuity.** Not usable as rails |
| Pi link | 2 × `1×20` female strips cut from `1×40` (bill 884), side by side = a 2×20 header. **Verified: both seat flat on all 40 Pi pins** |

---

## 1. Coordinates — read this before anything else

Read off the board's own silkscreen, confirmed from photographs 2026-09-11:

| Axis | Marking | Count | Length |
|---|---|---|---|
| **Long, 150 mm** | **numbers 1 – 48** | 48 | 122 mm of grid + a ~14 mm oval-pad strip at each end |
| **Short, 100 mm** | **letters A–Z then A′–J′** | 36 | 91 mm of grid + ~4.5 mm margin each side |

**Origin is the `48, A` corner.** The oval strips are isolated pads (metered) — not rails,
and not part of the grid. *Forgetting the 14 mm strip outside number 48 is what put an
early layout 12 mm over the Ethernet jack; the grid is not the board edge.*

### Orientation, anchored to the Pi

**The header lies across the LETTERS: numbers 48 and 47, letters A → T.**

```
         letter  A   B   C  …                     T  …  Y  …  J′
              ┌───────────────────────────────────────────────┐
   number 48  │▓▓▓▓▓▓▓▓▓▓▓▓ 2×20 HEADER ▓▓▓▓▓▓▓▓▓│            │
   number 47  │▓▓▓▓▓▓▓▓▓▓▓▓ letters A → T ▓▓▓▓▓▓▓│            │
              │                                               │
              │ ┌ ─ ─ ─ ─ ─ ─ ─ ─ ─ ─ ─ ─ ─ ─ ─ ─ ─ ┐         │
   number 25  │ │        Pi 3B+  (under the board)   │         │
              │ └ ─ ─ ─ ─ ─ ─ ─ ─ ─ ─ ─ ─ ─ ─ ─ ─ ─ ┘         │
              │   ↑ µUSB / HDMI edge                          │
              │                                               │
              │        FREE BOARD — over open air             │
   number  1  └───────────────────────────────────────────────┘
            ↑ USB/Ethernet                          microSD ↑
              stick out ~23 mm                    end is ~38 mm
              PAST this edge                      inside this edge
```

| Anchor | |
|---|---|
| **Pi header pin 1** | **letter T** |
| **Pi header pin 39/40** | **letter A** |
| USB / Ethernet | project **~23 mm past the board's A-edge** — fully accessible, cannot foul |
| microSD end | ~38 mm inside the board's J′ edge |
| Numbers 47 → 25 | the Pi, underneath |
| Numbers 24 → 1 | free board over open air — **the working area** |
| Assembly footprint | ~**150 × 123 mm**, fits the 170 mm box |

Note the pin order: **Pi pin numbers run from letter T up toward letter A**, because the Pi's
pin 1 is at its microSD end. Counter-intuitive; write it on the board.

> ⚠ **Plug the micro-USB in BEFORE lowering the board.** The board roofs that edge by ~75 mm
> at 8.5 mm height. It fits, but you do not want to be feeding a plug under it. This goes
> away at deployment when 5 V moves to pins 2/4 (§2).

---

## 2. Power topology — settled 2026-09-11

> ⚠ **As of 2026-10-05 the diagram below is history, not the plan.** There is no LM2596 and
> the 9 V adapter has no role. **Pi:** the 5 V 2 A barrel adapter → `(47,W)` → pins 2/4, with
> 1000 µF at the feed (as built 2026-09-13). **Heater rail 41:** the *second* 5 V source (the
> USB charger with its lead cut short) via the HTR IN terminal, grounds joined at rail 45.
> The split-rail principle is unchanged.

Both adapters on hand are used, as two rails with a common ground. This is §8.3 of
`HANDOFF.md` built from parts already owned.

```
  5 V 2 A adapter ──────────────────────────▶  Pi        (~1.3 A peak)
  9 V 1.5 A adapter ──▶ LM2596 @ 5.00 V ────▶  MQ heaters only  (~0.4 A)
                                                └─ grounds common at the board GND rail
```

**Why not one supply.** The 9 V 1.5 A is the bigger source once bucked (13.5 W vs 10 W) and
could run everything. It must not: the whole point of the split is keeping the MQ heaters'
switching step load off the Pi's rail. One supply rebuilds fault F1/F2 with a nicer
regulator in the middle. Split, each adapter runs at about half its rating.

**Set the LM2596 to 5.00 V on the meter before it is connected to anything.** These ship at
arbitrary voltages, often 15–20 V.

### Pi 5 V: micro-USB now, direct later

> ⚠ **Correction 2026-09-13 — the Pi's 5 V never goes through rail 41.** Rail 41 is the
> **MQ heater rail**, fed from the LM2596. An earlier version of this section said "at
> deployment, link rail 41 to Pi pins 2/4" — that would put the heaters' switching load back
> on the Pi's supply and undo the whole split. **The Pi's 5 V adapter lands directly on
> `(47,T)` and `(47,S)` via its own terminal. Rail 41 stays heater-only. Only the grounds join,
> at rail 45.**
>
> **First power-on, 2026-09-13:** rail 43 read **3.26 V** from the Pi — board working. The
> monitor showed the rainbow screen then "no signal", which looked like undervoltage on the
> long micro-USB cable **but was not**: red LED steady, green LED blinking (normal boot). It is
> an HDMI setting issue, not power. **Micro-USB stays for the bench.** Both remaining adapters
> are round barrel plugs, so a GPIO feed would need a barrel socket or cut lead — deferred to
> deployment, with the rules above (USB unplugged, polarity metered, 2 A fuse).
Feeding 5 V into Pi pins 2/4 is better for the deployed instrument — a micro-USB plug on a
rooftop works loose and corrodes, and this rebuild exists to delete fragile connections. But
it bypasses the Pi's 2.5 A polyfuse, and the USB is convenient on the bench. So:

- **Now:** Pi on micro-USB. **The 5 V rail's link to Pi pins 2/4 is left unmade.**
- **At deployment:** add those two joints, fit a **2 A inline fuse**, stop using micro-USB.
- **Label those two pads:** `PI 5V — LINK AT DEPLOY ONLY. NEVER WITH USB.` Two supplies
  fighting is the one way to damage something here.

---

## 3. Layout map

```
  letter   A   C   E   G   I   K   M   O   Q   S   U   W   Y   A′  C′  E′  G′  I′
        ┌────────────────────────────────────────────────────────────────────────┐
   48   │▓▓▓▓▓▓▓▓▓▓▓ HEADER  pin39/40 ◄── A … T ──► pin 1 ▓▓▓▓│                  │
   47   │▓▓▓▓▓▓▓▓▓▓▓▓▓▓▓▓▓▓▓▓▓▓▓▓▓▓▓▓▓▓▓▓▓▓▓▓▓▓▓▓▓▓▓▓▓▓▓▓▓▓▓▓│                  │
   45   │══════════════════ GND RAIL ═══════════════════════════════════════════ │
   43   │────────────────── +3.3 V RAIL ───────────────────────────────────────  │
   41   │────────────────── +5 V RAIL ─────────────────────────────────────────  │
        │                                                                        │
   38   │   MCP3208                          │   I2C BREAKOUT                    │
   ..   │   pin 1 at (38, D)                 │   letters P → Y, numbers 38 → 33  │
   31   │   pins 1-8  letter D               │   BMP280 0x76 · OLED · DS3231     │
        │   pins 9-16 letter G               │                                   │
        │   C1 100nF  letter I, numbers 38-37│   R1 4k7  P → S  ┐ numbers 30-29  │
   28   │                                    │   R2 4k7  V → Y  ┘                │
   ..   │   MQ DIVIDERS R3-R6                │                                   │
   22   │   letters A → H                    │   free ADC: CH3 CH4 CH5 CH6 CH7   │
        │   C2 1000µF letters K → N, 28 → 25 │                                   │
        │          ANALOGUE ←────────────────┼────────────────→ DIGITAL          │
        │                                    divide at letter ~N                 │
    6   │══════ SCREW TERMINALS  MAST 8 │ SOIL 4 │ POWER 2 ══════════════════    │
    3   │══════ letters A → J′ along the number-1 edge, over air ═══════════     │
    1   └────────────────────────────────────────────────────────────────────────┘
```

Rails run **across the letters**, parallel to the header, so every tap from a header pin is a
short vertical hop. Drop spurs down the board where a component sits far from a rail.

**Which of numbers 48 / 47 is the odd Pi row is not predictable from here** — the Pi marks
pin 1 with a square pad. Identify it at dry-fit and write `ODD` / `EVEN` and a pin-1
triangle on the board before the Pi comes off.

### Which way round you are looking — READ THIS BEFORE ANY ASCII MAP

**The board is single-sided:** copper pads on one face, bare phenolic on the other. The header
bodies were fitted on the bare face and the tails soldered on the copper face, so **the copper
face points UP, away from the Pi, and the Pi sits under the bare face.** Components insert
from the bare side and are soldered from the copper side, as normal.

> ⚠ **Never take an orientation from "left" or "right" in a drawing.** The two faces are
> mirror images, so any ASCII map is correct on one face and backwards on the other. **Read
> the silkscreen letter printed beside the pad. That is the only statement that is true from
> both sides.** An attempt on 2026-09-12 to write down which face has letter A on which hand
> was wrong, and is deliberately not recorded here — the coordinate is the truth, the view is
> not.

**Consequence, found the same day:** inserting a DIP from the bare side with its notch toward
number 38 leaves you **no choice** about which column pin 1 lands in — the body must stay on
the bare face, so the chip cannot be flipped. The MCP3208 came out **pin 1 at (38, G)**, and
that is not an error to correct but the board's answer. The wiring was mirrored to suit.

### Component bodies: which side they mount on

The copper face is up and the **Pi is underneath the bare face**, so a part mounted the normal
way hangs *down into the Pi gap* — about 10 mm, less whatever the Pi has under that spot.

> **Rule: anything taller than ~6 mm mounts on the TOP (copper) side, standing up into the
> box's headroom.** Everything short mounts normally underneath.

- **Underneath (normal):** MCP3208 (~4 mm), resistors, ceramic caps.
- **On top:** **C2, the 1000 µF electrolytic** — that can is 15–20 mm tall and §3 currently
  places it at numbers 28→25, directly over the Pi, where it **cannot physically fit**. Also
  the screw terminals.

### Notation

**(number, letter)** — `(47, R)` is the pad in number-row **47**, letter-column **R**.
Numbers are the long 150 mm axis, letters the short 100 mm axis.

### The full 40-pad map — AS BUILT

Header soldered **2026-09-11** at **numbers 48 and 47, letters A → T**. Pi pin 1 is at
letter **T**; pin numbers run **T → A**, backwards from the letters. Number 48 carries the
ODD pins, number 47 the EVEN.

```
  letter    A   B   C   D   E   F   G   H   I   J   K   L   M   N   O   P   Q   R   S   T
  num 48   39  37  35  33  31  29  27  25  23  21  19  17  15  13  11   9   7   5   3   1
  num 47   40  38  36  34  32  30  28  26  24  22  20  18  16  14  12  10   8   6   4   2

  GND ->    G   .   .   .   .   .   .   G   .   .   .   .   .   .   .   G   .   .   .   .      (number 48 row)
            .   .   .   G   .   G   .   .   .   .   G   .   .   G   .   .   .   G   .   .      (number 47 row)
```

`G` marks a Pi ground pin (6, 9, 14, 20, 25, 30, 34, 39). With the board seated, all eight
of those pads are continuous with the metal USB/Ethernet shells — which is how the map was
verified rather than assumed.

### Pin map — every pad you need, by board coordinate

**Number 48 = the Pi’s ODD pins (1,3…39). Number 47 = EVEN (2,4…40).** The Pi’s pin-1 row is
its outer row, and that is the one landing on number 48, away from the Pi body. **Confirm on
first seating** and write it on the board.

Pin numbers run **T → A** (pin 1 at T, pin 39/40 at A):

```
  letter    T  S  R  Q  P  O  N  M  L  K  J  I  H  G  F  E  D  C  B  A
  num 48    1  3  5  7  9 11 13 15 17 19 21 23 25 27 29 31 33 35 37 39   ODD
  num 47    2  4  6  8 10 12 14 16 18 20 22 24 26 28 30 32 34 36 38 40   EVEN
```

| Signal | Pi pin | Pad(s) | Goes to |
|---|---|---|---|
| +3.3 V | 1, 17 | **(48, T)** + **(48, L)** | rail at number 43 |
| GND | 6, 20 | **(47, R)** + **(47, K)** | rail at number 45 - at least TWO |
| +5 V | 2, 4 | **(47, T)** + **(47, S)** | **Pi feed** from the 5 V 2 A adapter via `(47,W)` (2026-09-13). **Never** linked to rail 41 — see section 2 |
| SDA | 3 | **(48, S)** | I2C breakout |
| SCL | 5 | **(48, R)** | I2C breakout |
| 1-WIRE | 7 | **(48, Q)** | DS18B20 + R1 to 3V3 |
| DHT-DATA | 16 | **(47, M)** | DHT22 + R2 to 3V3 |
| MOSI | 19 | **(48, K)** | MCP3208 pin 11 Din |
| MISO | 21 | **(48, J)** | MCP3208 pin 12 Dout |
| SCLK | 23 | **(48, I)** | MCP3208 pin 13 CLK |
| CE0 | 24 | **(47, I)** | MCP3208 pin 10 CS |

### MCP3208 (DIP-16), pin 1 at (38, G) — AS BUILT 2026-09-12

Notch toward number 38. **Column G, numbers 38→31 = pins 1–8 = CH0–CH7** (all still bare).
**Column D, numbers 38→31 = pins 16 down to 9** — the whole working side.

| Pin | Pad | Net / goes to |
|---|---|---|
| 16 VDD | `(38, D)` | 3V3 rail |
| 15 VREF | `(37, D)` | 3V3 rail |
| 14 AGND | `(36, D)` | GND rail |
| 13 CLK | `(35, D)` | `(48, I)` — Pi pin 23, SCLK |
| 12 Dout | `(34, D)` | `(48, J)` — Pi pin 21, **MISO** |
| 11 Din | `(33, D)` | `(48, K)` — Pi pin 19, **MOSI** |
| 10 CS | `(32, D)` | `(47, I)` — Pi pin 24, CE0 |
| 9 DGND | `(31, D)` | GND rail |

`Din` takes MOSI and `Dout` takes MISO — the pair crosses over. This is the joint that gets
wired backwards.

```
  col   B    C    D         G
  43   ┃    ·   ═╤═ 3V3 tap enters column D
  41   ┃    ·    ┃  (both wires insulated across the 5 V rail)
  38   ┃    ●────● 16 VDD          1 CH0
  37   ┃    ·    ● 15 VREF         2 CH1
  36   ●────●────● 14 AGND         3 CH2
  35   ┃    ·    ● 13 CLK          4 CH3
  34   ┃    ·    ● 12 Dout         5 CH4
  33   ┃    ·    ● 11 Din          6 CH5
  32   ┃    ·    ● 10 CS           7 CH6
  31   ●────●────●  9 DGND         8 CH7
```

**Two insulated wires only** — `(43,D) → (38,D)` for 3.3 V, and `(45,B) → (36,B)` for ground.
Column B is a **ground spur**: one wire dropped from the GND rail past both other rails,
landing at 36, then bare from 36 down to 31. It exists so the chip's two ground pins need
**two** rail crossings between them instead of four.

**Bare staples:** `(38,D)–(37,D)` · `(36,B)–(36,C)–(36,D)` · `(36,B)→(31,B)` ·
`(31,B)–(31,C)–(31,D)`.

**C1** (100 nF ceramic, body marked `104`) stands in column C between numbers **38 and 36** —
5.08 mm, a standard 5 mm part. `(36,C)` is already ground from the staple; `(38,C)` staples
across to `(38,D)`. It sits ~3 mm from VDD and AGND, which is the only placement that works.

> **No socket was available, so the chip is soldered direct.** That means VDD↔GND can no
> longer be tested in isolation. The substitute check is that **3V3 rail ↔ GND rail must not
> buzz** — the chip's own leakage is megohms, so a buzz means a bridged staple or a shorted
> C1, never the chip.

## 4. Steps and gates

- [x] **1a** Header strips cut to 1×20, both seat flat on all 40 Pi pins
- [x] **1b** Micro-USB plug clears the overhang
- [x] **1c** Oval edge pads metered — isolated, not rails
- [ ] **1d** Passives metered: resistors ≈4.7 kΩ (two **matched pairs** set aside for the MQ
      dividers), ceramics marked `104`, electrolytics 1000 µF — note the polarity stripe
- [x] ~~**1e** LM2596 trimmed~~ — **not needed: power stays as built (decided 2026-10-05).**
      The LM2596 is only the last rung of the F1 fallback ladder (session step 6)
- [x] **1f** CR2032 reads **≥3.0 V** unloaded — **3.2 V, 2026-09-13.** Safe on the DS3231 module
      because it runs at 3.3 V: the module's charging path (diode + resistor from VCC) then sits
      below the cell voltage, so a non-rechargeable CR2032 is not charged

### Step 4 — the header
Use the Pi as the jig; it is the only thing that guarantees alignment.

- [x] Both strips on the Pi, board down on the tails, orientation per §1 — header across
      **letters A → T on numbers 48 and 47**
- [x] **Sight the Ethernet jack: it should stick out ~23 mm PAST the board’s A-edge.**
      If any board is over it, stop — the position is wrong
- [x] **Tack two pins only**, one at each far corner. 2 seconds each
- [x] **Pull the Pi off** — do not solder the other 38 with it attached
- [x] Check both strips sit flat and square; reheat a single tack to correct
- [x] Solder the remaining 38 tails. ~350 °C, **under 3 s per pad** (phenolic lifts pads)
- [x] Mark pin 1 with a triangle at **letter T**; write `ODD` / `EVEN` against numbers 48/47,
      and write `pin 1 → T,  pin 39/40 → A` on the board — the order is counter-intuitive
- [x] Re-seat on the Pi dry, confirm it still goes down clean

- [x] **2026-09-11 — bridge test PASSED.** Board off the Pi, every one of the 40 tails
      metered open against its neighbours in both rows. Do this *before* rails go on: with
      no rails fitted every pad is isolated, so a bridge is trivial to find. Afterwards it
      is not.
- [x] **2026-09-11 — map verified on the Pi.** Probed a metal USB shell against each pad;
      exactly the eight `G` pads beeped and nothing else. So **pin 1 is at letter T and
      number 48 is the ODD row** — measured, not assumed. Everything downstream depends on
      this, so it is recorded rather than re-derived.

### Step 5 — the rails
Order is **GND → 3.3 V → 5 V**. Solid core stripped from an old ethernet cable lies flat and
is ideal; failing that, drag solder pad to pad.

- [x] **Number 45, GND**, letters A → J′, one continuous flooded strip — **2026-09-12**
- [x] GND tied to Pi pins **6 and 20** — two pins, far apart. A thin shared return is a
      classic cause of F2
- [x] **Number 43, +3.3 V**, letters A → J′, tied to Pi pins **1 and 17** — **2026-09-12**
- [x] **Number 41, +5 V**, letters A → J′, tied to **nothing on the Pi**. Pads for pins 2/4
      left bare and labelled — **2026-09-12**

**Tap routing — decided 2026-09-12.** Both 3.3 V taps are *insulated*; they cross the GND
rail. The pin-1 tap leaves `(48,T)` and hops **sideways into column U** before going down,
landing on the rail at `(43,U)`. Letters U → J′ are empty board, so that route passes only
the GND rail — whereas straight down column T it would pass `(47,T)` = Pi pin 2 = **+5 V**,
and a 3V3↔5V short is the worst fault this board can carry. The pin-17 tap runs straight
down column L; it passes GPIO24 at `(47,L)`, a signal, harmless.

> **A rail's `A ↔ J′` continuity check proves the WIRE, not the JOINTS.** It passes with only
> the two end pads soldered. Walk one probe down every pad ring in the row against a fixed
> probe on the rail — a pad that is touching the wire but not bonded reads open, and will
> pass every bench test until vibration finds it. Caught on the GND rail, 2026-09-12.

### ⛔ GATE — board OFF the Pi, before it is ever powered

| Check | Must read |
|---|---|
| GND ↔ 3V3 | **open** |
| GND ↔ 5V | **open** |
| 3V3 ↔ 5V | **open** |
| each rail, letter A to letter J′ | **short** |
| Pi pin 6 pad ↔ pin 20 pad | **short** |
| Pi pin 1 pad ↔ pin 17 pad | **short** |

- [x] **All seven pass — 2026-09-12.** Board is now safe to power.

A shorted rail found with a meter costs nothing. Found after power-up it costs the Pi.

### Step 6 — components
- [x] MCP3208 pin 1 at **(38, G)**, notch toward number 38 + C1 in column C — soldered
      2026-09-12, **SPI wires fitted and ADC gate PASSED 2026-09-13**
- [ ] R1 (1-Wire → 3V3), R2 (DHT22 → 3V3 — **check the module isn't already fitted with one**, U6)
- [ ] R3–R6 MQ dividers, matched pairs; put the measured `(R1+R2)/R2` into `sensors/config.py:26`
- [ ] C2 1000 µF on the 5 V rail (41, the heater rail), polarity checked
- [ ] **LDR divider:** 4.7 kΩ from CH4 `(34,G)` to the GND rail (the LDR itself goes from
      3V3 to CH4 via its terminal). Bright = low LDR resistance = high reading
- [ ] **Raindrop:** its terminal's AO way straight to CH3 `(35,G)`. No divider: the module runs on 3.3 V
- [ ] Every net buzzed against sheet 1 (`docs/drawings/schematic.svg`). Sheet 1 predates
      CH3/CH4 and the new cable map; the table below is the truth until it is regenerated

### Step 7 — terminals (new map, 2026-10-05: replaces the 14-way mast/soil/power plan)
Eight 3-way blocks = 24 ways, **20 used**. Placement as before: numbers 6 → 3, along the
number-1 edge (adjust if the paper test in session step 1 wants another edge).

| Block | Way | Carries | Board side |
|---|---|---|---|
| **SEN** (sensor CAT5e, ≈0.6 m) | 1 | DHT22 VCC | rail 43 (3V3) |
| | 2 | DHT22 GND | rail 45 |
| | 3 | DHT22 DATA | `(47,M)` GPIO23, + R2 to 3V3 if the module lacks one (U6) |
| | 4 | MQ heater +5 V | rail 41 |
| | 5 | MQ heater GND | rail 45 |
| | 6 | MQ-7 AOUT | R3/R4 divider → CH0 `(38,G)` |
| | 7 | MQ-135 AOUT | R5/R6 divider → CH1 `(37,G)` |
| **SOIL** (CAT5e, ≈1 m) | 1 | DS18B20 red + probe VCC | rail 43 |
| | 2 | DS18B20 black + probe GND | rail 45 |
| | 3 | DS18B20 yellow | `(48,Q)` GPIO4, + R1 4.7 kΩ to 3V3 |
| | 4 | soil AOUT | CH2 `(36,G)` |
| **RAIN** | 1 / 2 / 3 | VCC / GND / AO | rail 43 / rail 45 / CH3 `(35,G)` |
| **LDR** | 1 / 2 | LDR top / LDR bottom | rail 43 / CH4 `(34,G)` |
| **HTR IN** | 1 / 2 | +5 V / GND from the **second** 5 V source | rail 41 / rail 45 |
| **DEW** | 1 / 2 | to 8 × 220 Ω in parallel at the lens ring (≈0.9 W) | rail 41 / rail 45 |

Spare: SEN 8–9, SOIL 5–6. The Pi's own 5 V stays on its direct `(47,W)` feed, not a terminal.

- [ ] 20 ways fitted and buzzed to their pads
- [ ] **Every way labelled on the board in indelible pen.** The masking-tape flags on the
      demo build are why this rebuild exists

### Step 8 — bring-up
- [x] **ADC proven 2026-09-13** — CH0 swings 0 ↔ 4095 on a jumper, CH1/CH2 unaffected
- [ ] On the Pi. `python3 tests/test_all.py --skip camera`
- [ ] Sensors **one at a time**: I2C trio → MCP3208 + soil → DS18B20 → DHT22 → MQ pair

---

## 5. Session log

### 2026-09-13 (cont.) — GPIO power, undervoltage persists, "buck" is a boost
- **Pi now powered through its GPIO pins.** 5 V 2 A barrel adapter, red → `(47,W)`, black →
  `(45,Y)` on the GND rail; insulated `(47,W)→(47,T)` Pi pin 2, staple `(47,T)–(47,S)` pin 4.
  Cable taped for strain relief. All checks passed; `(47,T)` read 5.2 V; **micro-USB removed.**
  **Rail 41 is not involved** — it stays the heater rail.
- Pi boots, monitor and SSH work (`iesh.local` / `192.168.5.100`). SPI already enabled in
  `config.txt`; `/dev/spidev0.0` present.
- **Undervoltage NOT fixed.** `throttled=0x50005`, `hwmon: Undervoltage detected` flickering
  every few seconds **even at idle** — though `(47,T)` meters **5.17 V** under load. The meter
  shows an average; the Pi trips on millisecond dips. The long micro-USB cable was not the
  whole cause — **the adapter is.** F1 is still open.
- **U5 was wrong.** The module believed to be an LM2596 buck reads **`LM2587S`** — a boost. With
  12 V in it gave 30 V and would not trim below ~11.2 V. **Nothing was connected to its output.**
  Needs a real LM2596 (~₨150–200, SLT). Plan once bought: **12 V 2 A → LM2596 @ 5.20–5.25 V →
  Pi leads**, the buck's screw terminals becoming the point where the board unplugs for the box.
- **Decision: no buck converter will be bought.** Power is built from what is on hand:
  **5 V 2 A barrel adapter → Pi via GPIO**, with the 1000 µF capacitor at the feed to absorb the
  dips. If undervoltage persists, the next try is the known-good USB charger with its cable
  **cut short** and wired to the board, since the long cable — not that charger — was suspect.
  The MQ heaters (rail 41) will take whichever 5 V source is not feeding the Pi. The 9 V and
  12 V adapters and the LM2587S boost have no role in this build.
- **1000 µF capacitor fitted at the Pi feed**, + at `(46,W)` stapled to `(47,W)`, − at `(45,W)`.
  **Idle undervoltage gone** — only two dips during boot, then clean. **Under a 60 s 4-core
  load it still flags undervoltage continuously (`0x50005`).** The capacitor fixes transients,
  not a supply that cannot hold sustained current. F1 is improved, not closed.
- The Pi restarted once while `(47,T)` was being probed under load — no undervoltage showed in
  the samples just before it, so a probe slipping onto `(48,T)` (3.3 V) is the likely cause. A
  second restart was a deliberate unplug. **Rule: never probe the header pins with the Pi
  powered — measure the 5 V feed on the capacitor legs `(46,W)`→`(45,W)` instead.**
- **✅ ADC PROVEN END TO END** (`tests/test_mcp3208.py`). Floating, CH0–CH2 drift slowly
  0–420 (normal for unconnected inputs). **Jumper `(38,G)` → rail 43: CH0 = 4088–4095. → rail
  45: CH0 = 0000.** CH1 and CH2 did not follow, so the channels are isolated. This proves the
  header, both 3.3 V ties, the ground spur, C1, all four SPI wires and the chip together.

### 2026-09-13 — SPI wires in, ADC gate PASSED
- Started the ADC gate and found **group 3 (chip → header) all silent**: the four SPI wires
  had never been fitted. Continuity needs no power, so silence was a real open, not a quirk.
- **SPI wires fitted:** `(35,D)→(48,I)`, `(34,D)→(48,J)`, `(33,D)→(48,K)`, `(32,D)→(47,I)`.
- **The pin-17 3.3 V tap `(48,L)→(43,L)` pulled out** while working near the header.
  Re-soldered with slack in the wire, then re-ran every check near the header — including
  `(48,T)↔(47,T)` open and all SPI header pads open to their neighbours. All pass.
- **Meter lesson — readings of `600`–`800` in continuity mode are diodes, not shorts.** The
  meter shows millivolts across the path. Every MCP3208 pin has an internal protection diode
  to VDD (the 3.3 V rail), so SPI and CH pads read ~700 against rail 43. **Test: swap the
  probes.** A diode reads ~700 one way and `1` (open) the other; a real short reads near 0
  both ways. Confirmed on the bench.
- **ADC gate PASSED — all five groups.** Board is ready for first power-on.

### 2026-09-12 — all three rails in, MCP3208 fitted
- **GND rail soldered at number 45**, letters A → J′, bare solid copper laid on the pads.
  Tapped to Pi pin 6 at `(47,R)` and pin 20 at `(47,K)` — two ties, far apart, deliberately.
  Both pins are already one net inside the Pi; the second tie exists to halve the return
  resistance and survive a cracked joint, not to make a new connection.
- **Lesson, caught on this rail:** the `A ↔ J′` continuity check passes with only the two end
  pads soldered, because it measures the wire. Several mid-run pads were sitting on the wire
  unbonded. Re-flowed, then verified pad-by-pad. Recorded in §4 so it is not re-learned.
- **+3.3 V rail soldered at number 43**, letters A → J′, tapped to Pi pins 1 and 17 with
  *insulated* wire over the GND rail. Pin-1 tap routed via column U — see §4.
- Bare solid copper used throughout rather than stripped ethernet core; the board had plenty
  on hand. Solder is rosin-cored, so no flux pen was needed — the rule that replaced it is
  **fresh solder at every joint, never drag an old blob**, since remelted solder has no flux
  left and that is what makes the grey high-resistance joints that are fault F2.

### 2026-09-11 — header in, map verified
- Board chosen: blank `PY-10CM*15CM`, **uncut**. Old demo board set aside intact — bill 884
  bought a second MCP3208, so nothing has to be desoldered from it.
- Coordinates established from the silkscreen: **numbers 1–48 on the long 150 mm axis,
  letters A–Z/A′–J′ (36) on the short 100 mm axis**, origin at the `48, A` corner.
- **Two wrong turns worth remembering.** First, a layout put the board 12 mm over the
  Ethernet jack: the arithmetic used the 122 mm *grid* and ignored the ~14 mm oval-pad strip
  outside number 48 — *the grid is not the board edge.* Second, the fix proposed was to
  rotate the header; that was also wrong, and the right answer was the user's — run the
  header **across the letters**, which puts the USB and Ethernet ~23 mm clear of the board
  entirely and removes the collision rather than tuning around it.
- Female strips cut from `1×40` to `1×20`; both seat flat on all 40 Pi pins.
- **Header soldered: numbers 48 and 47, letters A → T.**
- **Bridge test PASSED** — all 40 tails open to their neighbours, done before any rail went
  on, while every pad was still isolated.
- **Map verified PASSED** — USB shell probed against each pad, exactly the eight `G` pads
  beeped. **Pin 1 is at letter T; number 48 is the ODD row.** Measured, not assumed.
- Power topology settled (§2): both adapters, split rail, Pi on micro-USB for now.

---

## 6. Open

- **Power as built, for deployment too (2026-10-05, user decision):** 5 V 2 A adapter via GPIO + 1000 µF. Idle clean, sustained load still undervolts. **Software trims now in `scripts/pi_config.sh`:** `arm_freq=1000` and `dtoverlay=disable-bt` (then `systemctl disable hciuart`). The fallback ladder is in the session block, step 6. Re-check `vcgencmd get_throttled` before the 24 h gate (F5).
- **No buck converter, by decision (2026-09-13).** Module on hand is an LM2587S boost; not buying an LM2596.
- **F1 undervoltage still present** on the 5 V 2 A adapter via GPIO (`0x50005`).
- **`docs/drawings/perfboard.svg` is stale** — generated for 57 × 37 ascending columns. This
  board is 48 × 36 descending. Regenerate `scripts/gen_drawings.py` to match §3.
- **The CAD is stale.** `roofbox.scad` and `roofbox_check.py` still model the old
  120 × 120 × 180 box *and* a 65 × 70 HAT; the ribbon check is invalid for this board. See HANDOFF §0.1.
- **Camera ribbon:** keeping the 110 mm one (2026-10-05). The only reach is Pi-on-wall, USB end up (HANDOFF §0.1). A 30 cm ribbon is in stock at Himalayan Solution if the paper test fails.
- **Passives not yet metered** (1d) — resistors need two *matched pairs* picked out for the
  MQ dividers, and the measured `(R1+R2)/R2` written into `sensors/config.py:26`.
- ~~LM2596 not yet trimmed~~ — not needed; power stays as built (2026-10-05).

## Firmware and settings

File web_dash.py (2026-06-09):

from flask import Flask, render_template, jsonify
import sqlite3

app = Flask(__name__)
DB_PATH = '/home/pawan/iesh_data.db'

def get_db_data():
    try:
        conn = sqlite3.connect(DB_PATH)
        conn.row_factory = sqlite3.Row
        c = conn.cursor()
        # Grab the 50 most recent logs
        c.execute("SELECT * FROM sensor_logs ORDER BY timestamp DESC LIMIT 50")
        rows = c.fetchall()
        conn.close()
        # Reverse the list so the oldest is first (better for graphs)
        return [dict(row) for row in rows][::-1]
    except Exception as e:
        print(f"DB Error: {e}")
        return []

@app.route('/')
def index():
    return render_template('index.html')

@app.route('/api/data')
def data():
    history = get_db_data()
    latest = history[-1] if history else None
    return jsonify({'latest': latest, 'history': history})

if __name__ == '__main__':
    # host='0.0.0.0' allows devices on the Wi-Fi hotspot to see the server
    app.run(host='0.0.0.0', port=5000, debug=True)

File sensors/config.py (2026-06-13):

# Single source of truth for all hardware config.
# Change values here; everything else imports from this file.

# GPIO Pins
DHT22_PIN        = 23   # GPIO 23
DS18B20_BASE_DIR = '/sys/bus/w1/devices/'

# I2C Addresses
I2C_BUS     = 1
BMP280_ADDR = 0x76
OLED_ADDR   = 0x3C
RTC_ADDR    = 0x68   # DS3231

# SPI / MCP3208 Channels
SPI_BUS         = 0
SPI_DEVICE      = 0   # CE0
SPI_SPEED_HZ    = 1_000_000
CH_MQ7          = 0   # MQ-7  CO sensor
CH_MQ135        = 1   # MQ-135 AQI sensor
CH_SOIL         = 2   # Capacitive soil moisture

# MQ Sensor Voltage Divider
# Two 4.7kΩ resistors halve the MQ AOUT (0–5V) to 0–2.5V safe for VREF=3.3V.
# MQ_DIVIDER_RATIO corrects ADC voltage back to the true sensor output voltage.
# MQ_VCC is the sensor supply (heater + AOUT reference).
MQ_DIVIDER_RATIO = 2.0   # (R1+R2)/R2 = (4.7+4.7)/4.7
MQ_VCC           = 5.0   # V — sensor supply rail
# MQ_RL: load resistor on the MQ module board (1kΩ on most blue modules).
# Used to compute RS = MQ_RL * (MQ_VCC / sensor_voltage - 1).
# Check your module datasheet or measure with multimeter between AOUT and GND
# with sensor disconnected. Leave as None if unknown — RS won't be computed.
MQ_RL_OHM        = 1000  # Ω — adjust if your module differs

# OLED
OLED_WIDTH  = 128
OLED_HEIGHT = 64

# Soil Moisture Calibration
# Run scripts/calibrate_soil.py to update these values.
SOIL_DRY = 4021   # raw ADC reading in dry air
SOIL_WET = 1673   # raw ADC reading fully submerged in wet soil

# Location & Altitude
NODE_LOCATION = 'HICS Station, Nepal'
SEA_LEVEL_HPA = 1013.25   # reference sea-level pressure for altitude calc

# Database
DB_PATH = '/home/pawan/hics-data/hics.db'

# MQ clean-air calibration (R0 baselines) — written by scripts/calibrate_mq.py
MQ_CAL_PATH = '/home/pawan/hics-data/mq_cal.json'

# Remote API
# API_KEY is printed once by: python manage.py seed_hics (on the website server)
# API_NODE_ID is the station_id the API key is registered to.
API_URL          = 'https://himalayansciences.org/api/v1/ingest/environmental/'
API_KEY          = ''           # set once you have the key from seed_hics output
API_NODE_ID      = 'IESH-KMC-001'
FIRMWARE_VERSION = 'v0.1.0'    # increment when hardware or software changes

# Network
HOTSPOT_SSID   = 'IESH_Hub'
HOTSPOT_IP     = '10.42.0.1'
HOTSPOT_IFACE  = 'wlan0'
INTERNET_IFACE = 'wlan1'

# Timing
OLED_CYCLE_SECS = 5    # seconds between OLED screen switches
DB_LOG_SECS     = 60   # seconds between SQLite writes
UPLOAD_SECS     = 300  # seconds between API uploads (5 min)

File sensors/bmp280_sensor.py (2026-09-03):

import struct
import smbus2
from .config import I2C_BUS, BMP280_ADDR


class BMP280Sensor:
    """Direct BMP280 driver via smbus2.

    The pimoroni `bmp280` library left the chip in sleep mode with
    measurements skipped (ctrl_meas=0x00), so the data registers never
    refreshed and every read returned the same stale pressure forever.
    This driver puts the chip in continuous (normal) mode at init and
    compensates readings per the Bosch datasheet (float variant).
    """

    REG_ID        = 0xD0
    REG_CTRL_MEAS = 0xF4
    REG_CONFIG    = 0xF5
    REG_DATA      = 0xF7
    REG_CALIB     = 0x88
    CHIP_ID       = 0x58

    def __init__(self):
        self.ok = False
        self.error = None
        self.last_raw_p = None
        try:
            self._bus = smbus2.SMBus(I2C_BUS)
            self._addr = BMP280_ADDR
            cid = self._bus.read_byte_data(self._addr, self.REG_ID)
            if cid != self.CHIP_ID:
                raise RuntimeError(f"chip id 0x{cid:02X}, expected 0x58")
            self._read_calibration()
            self._configure()
            self.ok = True
        except Exception as e:
            self.error = str(e)

    def _configure(self):
        """Put the chip in continuous mode. Separated out so reinit() can
        re-run it after a brownout resets the chip into sleep."""
        # config: standby 500 ms, IIR filter x4 (smooths pressure noise)
        self._bus.write_byte_data(self._addr, self.REG_CONFIG, 0x88)
        # ctrl_meas: osrs_t=x2, osrs_p=x16, mode=normal (continuous)
        self._bus.write_byte_data(self._addr, self.REG_CTRL_MEAS, 0x57)

    def reinit(self):
        """Re-open the bus and reconfigure. Called by the core loop when the
        chip is absent or frozen, so a device that drops off the I2C bus and
        comes back recovers on its own — v0.1 latched ok=False at init and
        stayed dead for the whole service lifetime."""
        try:
            try:
                self._bus.close()
            except Exception:
                pass
            self._bus = smbus2.SMBus(I2C_BUS)
            cid = self._bus.read_byte_data(self._addr, self.REG_ID)
            if cid != self.CHIP_ID:
                raise RuntimeError(f"chip id 0x{cid:02X}, expected 0x58")
            self._read_calibration()
            self._configure()
            self.ok = True
            self.error = None
            return True
        except Exception as e:
            self.ok = False
            self.error = str(e)
            return False

    def _read_calibration(self):
        raw = bytes(self._bus.read_i2c_block_data(self._addr, self.REG_CALIB, 24))
        # T1,P1 unsigned; the rest signed; all little-endian 16-bit
        (self._T1, self._T2, self._T3,
         self._P1, self._P2, self._P3, self._P4, self._P5,
         self._P6, self._P7, self._P8, self._P9) = struct.unpack(
            '<HhhHhhhhhhhh', raw)

    def read(self):
        """Returns (temperature_C, pressure_hPa) or (None, None) on failure.

        `last_raw_p` holds the uncompensated pressure word from this read, for
        the caller's frozen-register check (see sensors/health.Channel).
        """
        if not self.ok:
            return None, None
        try:
            d = self._bus.read_i2c_block_data(self._addr, self.REG_DATA, 6)
            raw_p = (d[0] << 12) | (d[1] << 4) | (d[2] >> 4)
            raw_t = (d[3] << 12) | (d[4] << 4) | (d[5] >> 4)
            self.last_raw_p = raw_p
            if raw_t in (0, 0x80000, 0xFFFFF):
                # Skip value = chip reset to sleep mode (undervoltage brownout
                # does this). Re-arm continuous mode; next read will be live.
                self._configure()
                return None, None

            # Bosch datasheet float compensation
            var1 = (raw_t / 16384.0 - self._T1 / 1024.0) * self._T2
            var2 = ((raw_t / 131072.0 - self._T1 / 8192.0) ** 2) * self._T3
            t_fine = var1 + var2
            temp = t_fine / 5120.0

            var1 = t_fine / 2.0 - 64000.0
            var2 = var1 * var1 * self._P6 / 32768.0
            var2 = var2 + var1 * self._P5 * 2.0
            var2 = var2 / 4.0 + self._P4 * 65536.0
            var1 = (self._P3 * var1 * var1 / 524288.0
                    + self._P2 * var1) / 524288.0
            var1 = (1.0 + var1 / 32768.0) * self._P1
            if var1 == 0:
                return temp, None
            p = 1048576.0 - raw_p
            p = (p - var2 / 4096.0) * 6250.0 / var1
            var1 = self._P9 * p * p / 2147483648.0
            var2 = p * self._P8 / 32768.0
            p = p + (var1 + var2 + self._P7) / 16.0
            return temp, p / 100.0
        except Exception as e:
            # Bus error mid-read: mark down so the core loop calls reinit().
            self.error = str(e)
            self.ok = False
            return None, None

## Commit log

2026-06-09 Initial commit: sync all HICS IESH v0.1 project files
    Pulls together all files from Raspberry Pi and dev machine into a
    single structured repo with a deploy workflow.
2026-06-09 Reorganize codebase: sensor modules, test suite, web/data layers
    - sensors/ package: one class per sensor, all config in sensors/config.py
    - tests/ suite: standalone diagnostic scripts per sensor + test_all.py master runner
    - data/ layer: unified SQLite schema (fixes web/core DB mismatch) + API uploader stub
    - web/ app: refactored Flask app with improved dashboard (all 7 sensor readings, Chart.js)
    - services/: updated systemd units pointing to /home/pawan/hics/
    - scripts/: calibrate_soil, sync_rtc, setup_hotspot (nmcli dual-WiFi)
    - core_dash.py: refactored to use sensor modules + upload integration
    - deploy.sh: updated paths, added --test flag to run hardware suite remotely
    - Archive old mon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
    [bmp280_sensor.py, calibrate_soil.py, config.py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]
2026-06-09 Fix BMP280 address back to 0x76 (confirmed by i2cdetect)
    i2cdetect confirmed: 0x3C=OLED, 0x57=AT24C32(DS3231 EEPROM),
    0x68=DS3231, 0x76=BMP280. Earlier 0x77 attempt was wrong.
    [config.py]
2026-06-10 Fix all 7 sensors: OLED driver, DHT22 retries, RTC bus handling
    OLED: replace luma i2c_rdwr path with direct smbus2 write_i2c_block_data
    (32-byte chunks). Corrected SH1106 init sequence — removed SSD1306-specific
    commands (0x8D charge pump, 0x20 memory mode) that were locking the bus.
    Added display off/on around page writes to match the known-working raw sequence.
    DHT22: added retry loop (5 attempts, 2.5s apart) since kernel 6.x bit-bang
    timing yields ~50% per-read success rate. Test updated to require 3/15 valid.
    RTC: DS3231 NAKs during 1-second register update; switched to fresh SMBus
    per read with 5 retries and 50ms between. Removed persistent bus object that
    was causing stale-fd fail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
    [dht22.py, oled.py, rtc.py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]
2026-06-10 Overhaul OLED, web dashboard, terminal dash; add WiFi and altitude
    OLED (core_dash.py + sensors/oled.py):
    - 6 screens: climate, soil+bar, air quality+bars, air temp sparkline,
    soil moisture sparkline, system status (RTC date/time + WiFi)
    - draw_bar() helper; draw_sparkline() now auto-scales if y_min/y_max
    not provided; labels min/max values at bottom of graph
    - DHT22 called with retries=1,delay=0 in main loop (non-blocking)
    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
2026-06-10 Correct MQ sensor voltages for 2x voltage divider; document RS calculation
    sensors/config.py:
    - MQ_DIVIDER_RATIO=2.0, MQ_VCC=5.0, MQ_RL_OHM=1000
    These are the physical constants for the perfboard voltage divider
    (two 4.7kΩ equal resistors → VOUT_adc = VOUT_sensor / 2)
    sensors/mcp3208.py:
    - read_voltage(): unchanged — returns raw ADC input voltage (post-divider)
    - read_sensor_voltage(): new — multiplies by MQ_DIVIDER_RATIO to recover
    the true sensor AOUT (0–5V); use this for any RS/R0 calculations
    - read_mq_rs(): new — computes RS = RL*(VCC/VOUT_sensor - 1) in Ohms;
    returns None if sensor near-zero (heater cold or unconnected)
    terminal_dash.py: shows corrected sensor volt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
    [config.py, mcp3208.py, terminal_dash.py]
2026-06-10 Add full web dashboard, learning portal, sky camera, and SD card tooling
    - Web dashboard (Flask): live sensor charts, sky camera widget, learning portal tiles
    - Sky camera: OV5647 capture + sky analysis (Pillow) + MJPEG live stream endpoint
    - Learning portal: 5 modules (climate, soil, air, data, environment), 25+ activities
    Grade 6-8 activities with live sensor visualizations (hz-gauges, data-bars, altitude-zones, sky-cam)
    - SD card tooling: flash.sh (dev machine), scripts/firstboot.sh (RPi first-boot auto-setup),
    hics-firstboot.service, setup.sh (idempotent RPi setup), requirements.txt
    - README: full project documentation, quick-start, troubleshooting guide
    - Fix DB_PATH to ~/hics-data/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
    [air.py, camera.py, climate.py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]
2026-06-11 feat: proxy AQI, BMP280 temp fallback, IESH_Hub hotspot on wlan1
    - sensors/air_quality.py: new module — MQ-7/MQ-135 datasheet curve fits,
    EPA-style CO sub-index, CO2-eq comfort bands, proxy AQI (worst-pollutant wins)
    - scripts/calibrate_mq.py: live clean-air R0 calibration (30-60s ADC sampling)
    - scripts/calibrate_mq_from_db.py: bootstrap R0 from existing DB nighttime
    rows (04:00-08:00 window) — no warm-up required
    - sensors/config.py: add MQ_CAL_PATH for mq_cal.json
    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
2026-06-12 security: remove all credentials and LAN details from the repo
    The repo is now public under hics-nepal. Remove every hardcoded
    credential and replace shared defaults with per-device values:
    - connect_wifi.sh: drop hardcoded home WiFi SSID/password defaults;
    prompt or take args instead
    - flash.sh: no default user password — generate a random per-device
    one when --password is not given; add --station-id / --api-key to
    provision cloud sync identity into sensors/config.py at flash time
    - setup_hotspot.sh: hotspot password is per-device (arg or generated),
    persisted to hics-data/hotspot_password.txt on the device only
    - deploy.sh: target via IESH_RPI env / iesh.local mDNS, not a LAN IP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
2026-06-13 feat: batch sync to HICS website API with backfill
    database.py: adds synced column (ALTER TABLE migration on startup),
    get_unsynced(limit), mark_synced(ids). log() explicitly sets synced=0.
    uploader.py: complete rewrite — correct endpoint, Token auth, proper field
    mapping (air_temp→temperature_c etc.), station_id in payload for auth lookup,
    drains full backlog in 500-row batches.
    config.py: FIRMWARE_VERSION = 'v0.1.0', correct API_URL and API_NODE_ID.
    [config.py]
2026-06-13 fix: update core_dash to call upload_unsynced() not upload()
    uploader.py was rewritten to batch-sync from DB (upload_unsynced); the
    main loop import was left pointing at the old single-row upload() function.
    [core_dash.py]
2026-06-13 fix: exclude sensors/config.py from rsync; add --pull option
    deploy.sh was silently overwriting the device API key with the empty
    repo placeholder on every full sync. sensors/config.py is now a
    permanent rsync exclude — each device manages its own key.
    Added --pull: ssh into Pi and git pull from GitHub + restart, for
    releasing committed code without a local rsync.
    Added .claude/ to excludes. Rewrote header to explain when to use
    deploy.sh vs git pull on the device.
2026-06-13 docs: update README — station ID, deploy workflow, cloud sync section
    - KTM-001 → IESH-KMC-001 throughout (flash.sh examples, option table)
    - Development Workflow rewritten: two-path model (deploy.sh vs git pull),
    table of when to use each, sensors/config.py protection noted
    - Project structure: sensors/config.py annotated as device-local/not committed;
    data/uploader.py annotated for batch backfill behaviour
    - New Cloud Sync section: how upload_unsynced() works, how to set the API key,
    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
2026-09-03 fix: gate sensor readings on freshness + plausibility; add Lalitpur build sheet
    v0.1 initialised every reading to 0.0 and overwrote only on success, so a dead
    sensor logged its last value forever, indistinguishable from data. Measured in
    the station's own DB: soil_temp = 441 rows of 0.0 plus 15 rows of 85.0 (the
    DS18B20 power-on-reset sentinel); pressure = 416 rows frozen at
    800.647395954495, bit-identical to 12 dp, against only 5 plausible rows. All of
    it reached the website.
    sensors/health.py (new): a Channel logs a value only if it is fresh AND
    physically plausible, else NULL. Bounds mirror _QUALITY_BOUNDS in the website's
    instruments/api.py, so a value the server would flag 'suspect' is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
    [bmp280_sensor.py, core_dash.py, ds18b20.py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]
2026-09-03 docs: handoff, 2D build drawings, and rooftop box CAD
    The 3D renders of the enclosure turned out to communicate almost nothing that
    was not already obvious, while the drawings you actually solder from were
    missing. So: two generated 2D sheets, and a handoff written for someone picking
    this up cold.
    scripts/gen_drawings.py (new) emits both sheets from one net list, so the
    schematic and the perfboard placement cannot drift apart:
    docs/drawings/schematic.svg — Pi 3B+ <-> protoboard <-> MCP3208 <-> screw
    terminals, every net named, with the passives that are not optional and a
    note that the Pi 3B+ already has 1k8 I2C pull-ups so no more must be added.
    docs/drawings/perfboard.svg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
    [gen_drawings.py]
2026-09-03 docs: add reference photos, transcribed parts inventory, dimension record
    Four photographs into docs/reference-photos/ (1400 px, ~850 KB total) so the
    documents stop depending on paths outside the repo:
    01-circuit-as-built-cardboard — fault F2 visually: dupont into dupont, joints
    held with masking-tape flags, no strain relief, and the power bank that was
    the original supply. This is what is being replaced.
    02-container-exterior — the found enclosure, 120 x 120 x 180 mm
    03-container-interior-gasket — the red silicone lid seal, which is why the
    container is usable and why the lid is the chassis plate
    04-camera-and-clipon-fisheye — the ~110 mm ribbon t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
2026-09-03 chore: drop a stray rasterised check image from docs/drawings
    schematic_check.png was a throwaway ImageMagick render used to eyeball the SVG
    during authoring. The SVGs are the deliverable; regenerate any raster with
    scripts/gen_drawings.py plus a converter.
    Claude-Session: https://claude.ai/code/session_01TheMCDo1Dagp7K7wLsYZix
2026-09-03 docs: consolidate into a single HANDOFF.md; document all four repos
    Replaces the HANDOFF.md / LALITPUR-DEPLOYMENT.md split. The two documents had
    grown duplicate copies of the fault table and the power section, which is the
    drift hics-docs/WORKING-AGREEMENT.md exists to prevent — and it meant a reader
    had to know which of the two was authoritative for any given fact. Now one
    document, 20 sections, with a linked table of contents.
    New section 1 covers the repos and where truth lives, because a fresh session
    cannot re-derive any of it:
    hics-docs/ the institute hub; the decisions that bear on this work
    (G9 - MQ stays a labelled proxy, which is why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
2026-09-03 docs: tighten the HANDOFF intro
    Dropped the note about replacing an earlier two-document split - historical
    noise for a reader who never saw it - and replaced it with a reading order.
    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
2026-09-03 fix(health): frozen-register gate only on a raw word; drop BMP280 air_temp fallback; station-side gate tools
    - health.Channel: frozen detection ran on the compensated value when no raw
    was supplied, so a steady DS18B20 (0.0625 C steps) or DHT22 (0.1 steps)
    was declared frozen and logged NULL. Now only when the caller passes raw.
    Two regression tests; 23 checks pass.
    - core_dash: the BMP280 sits inside a box that runs 45-55 C in sun, so it
    is no longer used as an air_temp fallback; ADC channels get None when
    SPI never opened instead of a plausible 0.
    - tests/test_all.py: --skip/--only, bring-up order from HANDOFF s14.
    - scripts/pi_config.sh: idempotent config.txt edits for s11 (--dr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
    [core_dash.py, gate_check.py, health.py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]
2026-09-03 docs: audit pass - CAD moved in-repo and revised, four generated sheets, bench page, HANDOFF corrections
    CAD (docs/cad/, moved from iesh-production-reference which is unversioned):
    - camera on a printed tower through the hood (flush in the lid it saw a
    75 deg cone); lens under a lip, not in a sky-facing cup
    - hood is a free-standing table on the paving tile: the draft bolted its
    legs through the lid on the gasket channel
    - no lid holes: standoffs bonded, ties on adhesive mounts; the tower bore
    waits for the camera. PG7 hole corrected to 12.5 mm (was the cable size)
    - whole-site model (tile, mast, vase, cable runs) -> cable cut lengths
    - roofbox_check.py: clash/field/height/sky/ribbon/l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
    [roofbox.scad]
2026-10-05 docs: BOARD-BUILD working doc; perfboard sheet for the 100x150 board
    BOARD-BUILD.md is the live bench doc for the v0.2 HAT built 2026-09-11 to
    09-13: the board's own A-Z/A'-J' x 48->1 coordinates, the as-built header,
    rails and MCP3208 map, the split power topology, gates and the session log.
    gen_drawings.py sheet 2 now targets the blank 100 x 150 board instead of the
    65 x 70 carrier-hat footprint; perfboard.svg and bench.html regenerated.
    Known stale (BOARD-BUILD §6): sheet 2 is laid out on 57 x 37 ascending
    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
2026-10-05 docs: rooftop site plan rev 6; HANDOFF §0.1 points to it
    docs/rooftop-plan.html is the site plan worked out 2026-10-05 once the roof
    was described (1000 L tank on a ~1 m iron stand, crows and monkeys): one
    compact unit in the existing box, camera in the lid, Pi + HAT on the inside
    wall, sensors within ~0.5 m, cable map, risks, the sky-object pipeline and a
    gated build order.
    HANDOFF §0.1 records the settled decisions and marks §7/§10/§12/§13 as
    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
2026-10-05 docs: prepare the next bench session; F1 trims in pi_config.sh
    BOARD-BUILD "▶ NEXT SESSION" rewritten for the 2026-10-05 plan:
    paper-strip ribbon test (Pi on the wall, USB end up), passives incl.
    220-330 ohm for the dew heater, step 6 components with the LDR divider
    (CH4) and raindrop (CH3), power check under camera load with its
    fallback ladder, sensors one at a time, and the firmware tasks that need
    no hardware (CH3/CH4, Pi temperature and throttle health channels,
    INTERNET_IFACE).
    Step 7 is a new 20-of-24-way terminal map (SEN, SOIL, RAIN, LDR, HTR IN,
    DEW) replacing the 14-way mast/soil/power plan. Stale items corrected:
    the pin-map +5 V row (pins 2/4 now carry the Pi feed), 1e (no LM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
